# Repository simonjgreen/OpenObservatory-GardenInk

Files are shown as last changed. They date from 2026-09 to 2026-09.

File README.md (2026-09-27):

# Open Observatory · Garden Ink

An illustrated e-ink display for [Open Observatory](https://github.com/simonjgreen/OpenObservatory). A Raspberry Pi Zero, a printed frame, and an hourly account of what the garden has been up to.

**Garden Ink is an expansion of Open Observatory and depends on it for its data.** The outdoor station does the listening, identification and review. This is another way to see what it heard, on a screen that can sit in the kitchen and get on with it.

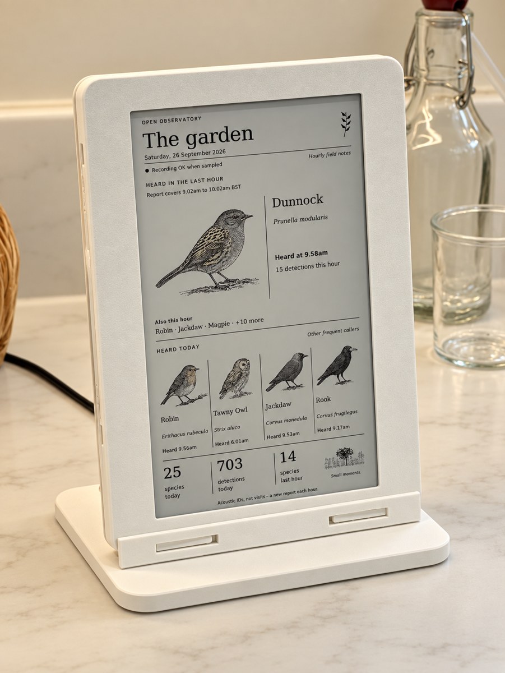
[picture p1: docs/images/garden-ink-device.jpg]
Garden Ink running on a portrait e-ink screen in its white printed Counterframe enclosure


*The assembled frame, running on the kitchen counter. The birds are illustrations of acoustic identifications.*

## Where the idea came from

I already had an [indoor LCD display for Open Observatory](https://github.com/simonjgreen/OpenObservatory#the-indoor-display): a small ESP32 touchscreen showing what the station was hearing outside. Then I saw [Fugleramme](https://github.com/arnegiacomo/fugleramme) on [Hacker News](https://news.ycombinator.com/item?id=49711544), and thought it'd be nice to have an e-ink version of my existing display. I mentioned [the LCD setup in the discussion](https://news.ycombinator.com/item?id=49719062).

Credit to [arnegiacomo](https://github.com/arnegiacomo) and Fugleramme for the e-ink idea. I already had the listening side working; seeing their bird frame made me want to give it a different sort of display. Garden Ink is the result.

## What it does

- Shows the latest qualifying identification from the last hour, alongside three other frequent species heard today, with wider cards for unusually long names.
- Uses the six-species Gallery for the 10am and 2pm local-time editions, returning to Journal at 11am and 3pm. Night mode takes priority; `gallery_hours` configures these daily slots.
- Refreshes on startup, then starts scheduled updates on the hour. `./service.sh refresh` requests an update between scheduled reports; startup and manual pushes retain a saved three-minute minimum between panel attempts. It shows the date and when things were heard; a clock that is wrong for most of the hour would be fairly unhelpful.
- Counts qualifying acoustic detections, with the station's review decisions and source filtering respected. Today starts at local midnight, including when the clocks change. If a scan is incomplete, the totals say so.
- Switches to a three-page bat and owl carousel after sunset when daytime bird detections fall and sustained bat activity or an owl is heard. It keeps the night edition until sunrise, with an owl portrait and bat illustration throughout. See [night mode](docs/design/NIGHT_MODE.md).
- Uses a Waveshare 7.3-inch Spectra 6 **HAT (E)** in 480 × 800 portrait orientation.
- Runs locally with cached artwork. Optional paid image generation is separate and disabled by default.
- Redraws the current page when one of its missing illustrations becomes available, retaining the three-minute panel guard and the regular report schedule.

One bird can produce plenty of detections, so the numbers aren't a count of individual birds or visits.

## The frame

The enclosure is called **Counterframe**. It stands on its own, prints in PLA and goes together without screws. There is one power lead into the Pi; everything else fits inside.

These are the four printed parts laid out before assembly: the front bezel, internal carrier, rear cover and stand.

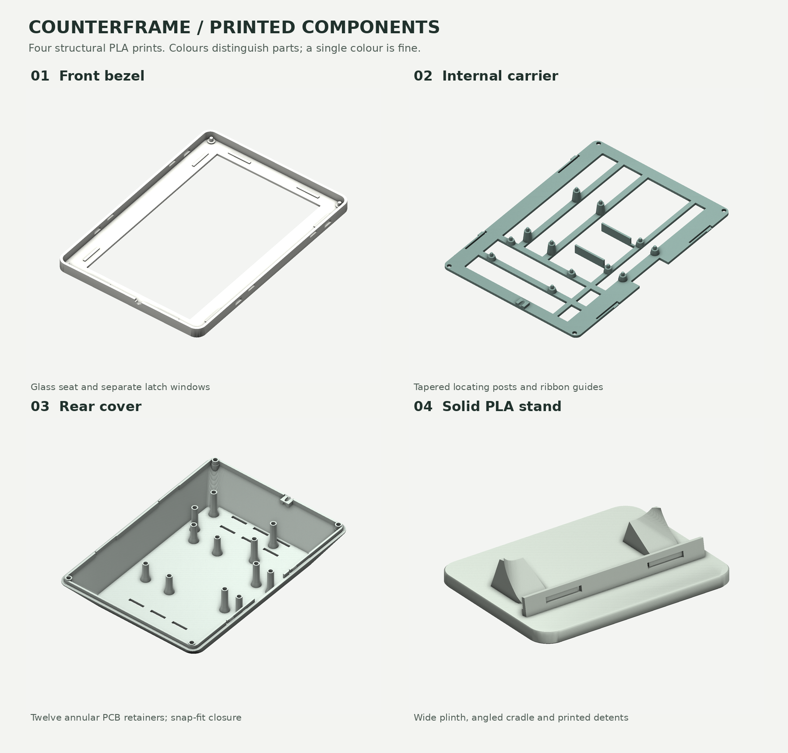
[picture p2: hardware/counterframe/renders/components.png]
CAD render of the four Counterframe parts laid out for assembly: front bezel, internal carrier, rear cover and stand


With the back removed, you can see where the Pi, display driver and adapter sit, and how the ribbon and power cable fit around them.

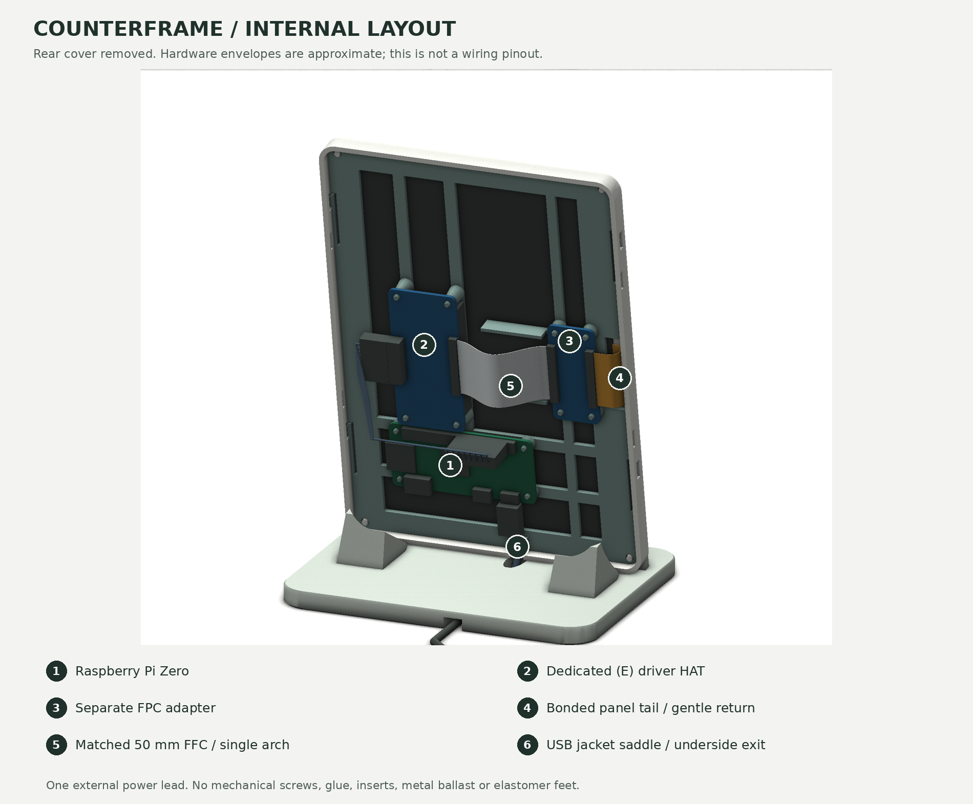
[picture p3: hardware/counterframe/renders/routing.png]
CAD render with the back removed, showing the Pi Zero, display driver, adapter, ribbon cable and USB power route


Both images are CAD renders from the [frame build guide](hardware/counterframe/README.md). The cable colours show the route through the case; use the [wiring table](docs/design/MECHANICAL.md#project-wiring) for the actual connections. The [OpenSCAD source and printable parts](hardware/counterframe/) are included.

## Requirements

You need a running [Open Observatory station](https://github.com/simonjgreen/OpenObservatory) that the display Pi can reach. Garden Ink reads its `/api/v1/health` and `/api/v1/detections` endpoints. The station is a separate installation; the [API contract](display/docs/API_CONTRACT.md) describes what the display expects from it.

The display requires a Pi Zero, Raspberry Pi OS, the specific HAT (E) panel and SPI wiring. Other Waveshare variants are not interchangeable. Workstation previews require Python 3.9+, Pillow and DejaVu fonts, with no station or API key.

## Try it on a workstation

```bash
git clone https://github.com/simonjgreen/OpenObservatory-GardenInk.git
cd OpenObservatory-GardenInk
python3 -m venv .venv
.venv/bin/python -m pip install -r requirements-dev.txt
make test PYTHON=.venv/bin/python
make preview PYTHON=.venv/bin/python
```

On Debian/Ubuntu, install `python3-venv`, `fonts-dejavu-core` and `fonts-dejavu-extra` if needed. Then open `local/previews/no-clock.png` to see the actual 480 × 800 output with labelled sample observations. You can try this without a panel, a live station or an API key.

## Install on a Pi

Copy `display/` to `~/garden_ink` on a fresh Pi, then run as the normal Pi user:

```bash
cd ~/garden_ink
./install.sh http://YOUR-STATION:8080
./run.sh --check
./run.sh --once
./service.sh install
```

For an existing device, first follow [deployment and backup](docs/operations/DEPLOYMENT.md). Preserve configuration, curated artwork, credentials, refresh state and the artwork spending ledger.

## Artwork

The original [robin](art_studio/reference/robin.png) is the reference for the ink-and-wash style. There are 47 bundled images, and the consistency still needs work. The workstation studio has a 53-species catalogue, with generation, review, approval and export. If you already have generated artwork, import it before paying to make it again.

The display works without an OpenAI key. New image generation is optional and paid, and the results need looking at: successfully producing a PNG says very little about whether the bird has the right number of legs. See the [artwork workflow](docs/artwork/WORKFLOW.md), [local recovery](docs/operations/LOCAL_RECOVERY.md) and [optional automatic artwork](docs/operations/AUTOART.md).

## Project layout

| Path | Contents |
|---|---|
| `display/` | Pi application, hardware driver, bundled illustrations and display tests |
| `art_studio/` | Workstation artwork tool and original style reference |
| `hardware/counterframe/` | OpenSCAD master, printable parts and illustrated build guide |
| `design/` | Selected visual reference and current renderer baseline |
| `docs/` | Current architecture, setup, maintenance and design guidance |
| `tests/`, `tools/` | Offline regression suites and development helpers |

The [documentation map](docs/INDEX.md) points to the detail. Next I want to improve the content, refresh timing, readability, power consumption and artwork. [Status and roadmap](docs/STATUS_AND_BACKLOG.md) records what works and what still needs checking.

## Contributing and licensing

See [CONTRIBUTING.md](CONTRIBUTING.md) for local checks and [SECURITY.md](SECURITY.md) for private reporting. Software is MIT-licensed; the enclosure is CC0. Artwork, photographs and third-party notices have separate terms described in [LICENSE.md](LICENSE.md).

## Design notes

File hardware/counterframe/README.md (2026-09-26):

# Counterframe / 7.3 E6

**Portrait countertop enclosure · four structural PLA prints · no screws**

Version 1.0 engineering prototype, 23 September 2026. Designed in OpenSCAD and exported to individual manufacturing STLs. The render images are produced from the same geometry, not concept illustrations of a different object.

> **Detailed physical fit qualification remains outstanding.** The project photograph shows an assembled device, but its exact print revision and measurements are not recorded. Published board outlines and mounting-hole positions have been checked; component heights, cable dimensions, bend suitability, print tolerances and real countertop stability still require first-article verification. Read the compatibility table before printing. Do not force the display or its bonded flex to fit.

## Design at a glance

The front is a softly rounded picture frame, with a 9 mm-deep perimeter and a rear housing that tapers to a smaller back face. The maximum enclosure depth is 34 mm. A separate low plinth holds the screen 10 degrees back from vertical. Boards are mounted beside one another rather than stacking the HAT on the Pi.

| Item | Nominal CAD dimension |
|---|---:|
| Front body | 134 × 188 mm |
| Maximum body thickness | 34 mm |
| Visible straight perimeter depth | 9 mm |
| Stand footprint | 142 × 108 mm |
| Main plinth thickness | 8 mm |
| Assembled height | Approximately 195 mm |
| Display opening | 96.8 × 160.8 mm, portrait |
| Image area | 96 × 160 mm, portrait |
| Shell wall / front face | 2.2 / 1.8 mm |
| Backward inclination | 10° |

The bezel centres the **visible image**, not the raw glass outline. The glass is offset by 2.9 mm relative to the image centre because the original panel's inactive borders are unequal. The wider side border also makes room for the bonded flex to return behind the display.

## Files

- `counterframe.scad`: editable master model; no external CAD library required.
- `stl/front.stl`, `carrier.stl`, `rear.stl`, `stand.stl`: print **one of each**.
- `stl/release_key.stl`: optional small PLA tool for pressing the release tabs.
- `stl/coupon_pins.stl`, `coupon_holes.stl`: peg-fit samples.
- `stl/coupon_latch.stl`, `coupon_socket.stl`: small snap-fit practice pieces.
- `renders/`: assembled, rear, side, internal, exploded and individual-part views.
- `BUILD_GUIDE.html`: illustrated offline guide; open in a browser.
- `validation.json`: mesh and nominal geometry check results, with their limitations.
- `export.sh`: reproduces the manufacturing STLs with the OpenSCAD CLI.
- `render.py` and `checks/export_render_meshes.py`: optional renderer; requires Python, VTK, NumPy and Pillow in addition to OpenSCAD. `reference/` contains **non-printing, approximate electronics and cable envelopes** used by it.

All manufacturing STLs are in **millimetres**, already oriented for printing. Do not merge them into a single print, scale them to fit a bed, or print the electronics reference meshes. The assembly and exploded selectors are for inspection, not a single printable object.

## Hardware compatibility: verify these first

This is specifically based on **Waveshare 7.3inch e-Paper HAT (E), E Ink Spectra 6**, with its separate small FPC adapter and dedicated blue driver HAT. It is **not** a claimed fit for the seven-colour (F), the four-colour (G), a generic e-Paper driver board, or a PhotoPainter board. [S1–S4]

| Hardware | Published outline / holes used | What still needs measuring |
|---|---|---|
| Display glass | 170.2 × 111.2 mm; active 160 × 96; model thickness 0.91 mm | Actual thickness, back-side features and allowable flex-bending region |
| Dedicated (E) HAT | 65 × 30.5 mm; 58 × 23 hole pitch; Ø3 mm holes | Underside header and top-side connector/switch heights |
| Small adapter | 45 × 21 mm; 38 × 14 hole pitch; Ø3 mm holes | Socket orientation, housing heights and any underside parts |
| Raspberry Pi Zero | 65 × 30 mm; 58 × 23 hole pitch; Ø2.75 mm holes | Your board revision, populated components and GPIO connector boots |

The Pi mounting pattern is taken from the official Pi Zero drawing. The component keep-out is a conservative **approximation**, not a manufacturer STEP model. A Zero 2 W may share the mounting outline, but this package does not certify every component of every Zero-family revision. Check your actual unit. [S5]

### Specific cable and connector assumptions

1. **One slim, straight micro-USB plug** into the Pi's **PWR IN** port. The modelled moulded body is 9.6 mm wide × 14 mm long × 5.6 mm thick; the cable jacket is Ø3.4 mm. A bulky boot, ferrite bead or right-angle connector is not an assumed fit. This does not add a USB-C panel socket or a USB extension inside the case.
2. **50 mm overall-length, 50-way FFC** between the adapter and HAT, with the correct pitch and contact-side arrangement for the kit. The modelled path is 50 mm including the seated ends. This is a **short interconnect**, not an attempt to fold a long kit cable into the case. The actual supplied cable length has **not** been established; obtain a matching short replacement when necessary. Measure yours; do not stretch a shorter cable to this route or compress a longer one into a tight crease. Preserve the manufacturer's contact orientation.
3. An eight-wire SPI/power lead connects the remote HAT to the Pi GPIO. The model permits female jumper housings extending 14 mm above the Pi header plastic. Follow the Waveshare pinout; the simplified wire colours and positions in the render are **not a wiring diagram**. No second external power supply is designed into the enclosure.
4. The short bonded panel tail is taken as 24 mm long × 25.5 mm wide from the drawing. Its modelled return has a **4.5 mm bend radius**. The separate 50 mm FFC follows one smooth arch with approximately 6.7 mm minimum modelled radius. These are **design assumptions, not manufacturer-approved minimum bend radii**. Reject the route if it would bend a stiffener, IC, bonded transition, or unsuitable portion of the actual tail. [S2, S6]

## How the retention works

### Front bezel and glass

The glass rests on its inactive front border inside broad lateral guides. It is captured between the bezel and the skeletal carrier with **0.15 mm nominal axial clearance** and **0.30 mm clearance per side**. There is no intended spring preload, press fit, conical peg contact or adhesive on the glass. The carrier must click home without squeezing or bowing it. The nominal backside air gap also separates the carrier crossbars from the glass.

### Internal carrier and boards

The carrier locates on four tapered bezel pins and locks into four side windows with long, in-plane flexure tabs. Each PCB sits on **four tapered-tip locating posts**. Their parallel locating portions are Ø2.50 mm for the Pi and Ø2.70 mm for the HAT and adapter. The taper is a lead-in, not a wedge driven into the PCB hole.

The rear cover has **twelve integral annular retaining collars** aligned with those posts. When the lid is fitted, these capture the mounting-hole lands from above with 0.15 mm nominal clearance. Central bores in the collars clear the peg tips. This separates lateral location from axial retention and avoids relying on friction in a PCB hole. The rear cover has separate hard stops over the four carrier fixings, relieved for the front locator tips.

The boards are intentionally **not retained against lifting while the cover is removed**. Assemble and service with the frame lying face-down, not standing vertically with loose boards hanging on pegs.

### Rear cover and stand

Four independent rear-cover snap tabs engage their own side windows. The front and carrier clips use different positions, so servicing the lid does not require releasing the glass carrier.

The stand has a fitted angled cradle, two rear buttresses and two detent leaves that engage recesses below the image. It is a separate part so its mass can be concentrated low down. Print it **solid PLA**: no metal ballast or rubber feet are required by the design.

PLA feet are not a substitute for rubber grip. The wide base is intended to resist tipping during modest movement, but the actual unit may slide on a polished or wet counter. This design has not been bump-, pull- or drop-tested. Lift it by the base rather than by the display bezel.

## Cable routing

Viewed **from the open rear**, the Pi is at the bottom, the driver HAT is above it on the left, and the small adapter is on the right.

- The display's short bonded flex exits the **right side in this rear view**, rounds back inside the side pocket and enters the adapter's outer socket. Seen from the front, this is the display's left edge.
- The white 50 mm FFC follows a single broad arch between the adapter and HAT. Its centreline travels monotonically from one socket to the other, so it has no crossing folds. It bends through its thickness, without an edgewise fold or twist. The carrier has fences beside this lane and the lid's retaining columns are outside the modelled route.
- SPI wires run left from the Pi **below the lower HAT mounting posts**, then up the left-hand side into the HAT's eight-pin connector. Do not pull them diagonally across the lid's collar positions.
- USB power enters the Pi directly, follows a shaped jacket saddle at the lower edge, and sweeps rearwards through the stand's open underside channel. The nominal jacket path uses **8 mm-radius bends**. Only this flexible jacket is lightly captured; the plug and PCB connector must not carry a cable tug.

The saddle follows the curved USB path and is split between the carrier and lid. A plug does not have to be pushed through a tiny printed hole. Its default groove is 0.10 mm smaller than the measured jacket diameter; set `cable_grip=0` initially when the jacket's compressibility is unknown. **Use the same setting to regenerate both carrier and rear cover.** Check that the jacket is held without flattening, cutting or levering the plug.

The cable guidance is not an industrial strain-relief rating. Leave slack behind the stand so a moved appliance or pulled lead does not load the micro-USB connector or topple the frame.

## Printing

Suggested starting point for a calibrated 0.4 mm-nozzle FDM printer:

| Part | Orientation in supplied STL | Starting settings / supports |
|---|---|---|
| Front | Visible face on bed | 0.16–0.20 mm layers, 4 perimeters, 5 top/bottom layers; no supports intended |
| Carrier | Flat grid on bed, posts upward | 0.16 mm layers, 4 perimeters, 100% infill; no supports intended |
| Rear | Outside back face on bed, collars upward | 0.16–0.20 mm layers, 4 perimeters, 5 top/bottom layers; no supports intended |
| Stand | Plinth on bed | 0.16–0.20 mm layers, 4 perimeters, **100% infill**; local PLA supports beneath the front detent leaves/tips |
| Coupons / key | As supplied | Same filament and fit-critical settings as the final parts |

These settings have **not** been sliced for your printer. Inspect the layer preview, especially the stand's free-ended detent leaves, cable-channel bridges and latch tips. Use local support painting rather than filling every cavity with support. Clear all support from the cable passage before inserting a cable.

A **200 × 200 mm usable bed** accommodates the largest 134 × 188 mm part, with a modest brim if the printer's actual usable area permits it. A 220 × 220 mm bed provides more margin. Do not scale parts to fit a smaller bed. Use filament-specific temperature settings and a clean bed; keep seams, first-layer bulges and support scars away from glass seats and mating faces.

Use ordinary unfilled PLA for the first article. Print coupons in the same spool and orientation. A decorative filament's snap behaviour can differ; no blend is certified here. Prusa notes PLA's relatively brittle behaviour and low temperature resistance. [S7]

### Calibration before the full build

The pin coupon has five nominal diameters, left to right along increasing X: **2.40, 2.50, 2.60, 2.70, 2.80 mm**. Its companion has three Ø2.75 and two Ø3.00 holes. Printed holes only indicate your printing process; they do not replace checking a real PCB hole. Gently test a suitable individual peg with the actual PCB, supporting it at the hole. A board should lower onto its posts without being forced or flexed.

For the latch coupon, place the male part on the socket's open floor with the long leaf next to its rear wall and press down until the small head enters the window. The male underside ends 1 mm above the socket's print-bed plane. Release by pushing the head inward through the window. This tests a similar in-plane PLA leaf, not the entire case or stand interface. Reject cracked, whitened or permanently distorted samples.

Dry-fit the four full-size printed parts **without electronics** before assembling the glass. All clips should engage with modest, local finger pressure. Do not compensate for a tight print by pushing harder through the screen. Correct dimensions or printing settings and reprint.

## Assembly order

1. Bench-test the Pi and display. Install the microSD card and any required GPIO header before enclosure assembly. Check every dimension in the compatibility section, the FFC contact orientation, and the physical bendable regions of both flex cables.
2. Print and test the coupons, then the four structural parts. Remove stringing and support debris; smooth only the relevant printed mating surfaces. Confirm the empty front, carrier, lid and stand fit without force.
3. Lay the front bezel face-down on a clean, protective work surface. Lower the glass into its seat, image toward the aperture, bonded tail to the right **as seen from the rear**. Keep dust and printing burrs off the glass support border.
4. Position the carrier on its four bezel locating pins. Keep the bonded tail outside the carrier's relieved side pocket. Engage the four carrier tabs using pressure on the perimeter near each clip, not the crossbars over the glass. Verify the display is not bowed or squeezed.
5. Place the Pi, HAT and adapter on their respective four locating posts. Check every PCB sits on its standoff shoulders, not on a component or cable. The HAT's factory underside header is retained; no desoldering is assumed.
6. Connect the panel tail to the adapter with a gentle return. Connect the 50 mm FFC and arrange the broad arched route. Insert and lock connectors according to the kit instructions. The full seated contact ends must remain straight; do not pull the bonded tail to gain reach.
7. Connect the eight-wire HAT lead to the Pi, following the manufacturer pinout. Route it around the left side of the HAT, below its lower retention-post positions. Plug the slim micro-USB lead into **PWR IN**, not the data USB port, and place its jacket in the curved lower saddle.
8. With the unit still face-down, lower the rear cover squarely. Make sure each annular collar surrounds a peg rather than landing on a component. Check the entire cable route before engaging all four lid clips. The cover must not require force to flatten a ribbon or push down a connector.
9. Lay the external USB lead into the stand's open underside channel. Seat the case into the angled cradle and engage the two front detents. Confirm the cable is not trapped between the case and the stand and does not lift the stand off the worktop.
10. Power up. Check a full image, then check temperature, stability, cable slack and the absence of glass pressure during normal use. Stop using the enclosure if the display changes when the frame is gently handled, a plug is under load, a latch cracks or the plastic distorts.

For service: unplug power; support the frame; release the two stand detents and remove the case. Lay it face-down. Press the rear-cover tabs inward using the supplied PLA key and lift the cover evenly. Do not pry between glass and bezel. Release the carrier only when the screen itself needs removal. Removing the lid also removes axial retention from the PCBs.

## Kitchen placement

This is a **vented indoor enclosure, not splash-proof, washable or IP-rated**. There is no transparent protective sheet over the display. Keep it away from the hob, oven exhaust, toaster, kettle plume, sink splashes and direct hot sunshine. Do not wash or immerse it. Prusa states that ordinary PLA can soften and deform above approximately 60°C; that is not an acceptable target operating temperature. [S7]

The solid base improves the distribution of mass but cannot guarantee resistance to a cable snag or a forceful knock. Confirm stability on your actual worktop, first with the screen supported. All-PLA construction deliberately excludes elastomer anti-slip feet.

## Editing and regenerating

Open `counterframe.scad`, select `part`, and use F6 to render. For a printable export choose `front`, `carrier`, `rear` or `stand`, then export STL. `assembly`, `exploded` and `section` are inspection views. Toggle `show_hardware` and `show_cables` for clarity.

```sh
# Reproduce all manufacturing STLs (OpenSCAD must be installed).
bash export.sh

# A single part, or a tolerance variant.
openscad -o carrier.stl -D 'part="carrier"' counterframe.scad
openscad -o rear_no_grip.stl -D 'part="rear"' -D 'cable_grip=0' counterframe.scad
```

The short FFC arch uses `ffc_arch_rise`; it is not a route for an arbitrary cable length. The most useful fit adjustments are `panel_t`, `panel_xy_clear`, `panel_z_clear`, `pi_peg_d`, `hat_peg_d`, `pcb_t`, `pcb_capture_clear`, `cable_d`, `cable_grip` and `fit`. Changing a mating dimension means regenerating **all affected parts**, not just one. Never shrink the glass pocket to obtain an interference fit.

This is an editable design for a particular hardware arrangement, **not a universally self-adapting enclosure generator**. Board positions, plug keep-outs and the arched-cable route include fixed values. Substantial dimension changes require checking those features and rerunning clearance checks. The optional Python studio renderer's transforms are set for this delivered version; update them for altered dimensions. OpenSCAD's own assembly view uses the live parameters.

## Validation scope

`validation.json` records the checks actually completed on the exported meshes. A watertight, single-body STL is not proof that a snap fit will survive printing or use. Nominal CSG interference checks use simplified hardware keep-outs, omit small components and solder details, and intentionally allow the specified USB jacket compression. They do not measure real strength, thermal behaviour, grip, electrical safety, cable bend limits, manufacturing variation or impact resistance.

Before relying on the enclosure, the remaining first-article checks are actual hardware fit; printing/slicing; latch engagement and release; no preload on the glass; fully seated, unstrained flex connectors; non-damaging USB capture; normal-use temperatures; and stability/cable-pull behaviour on the intended counter.

## Manufacturer references

Dimensions were checked against these primary sources on 23 September 2026. Published component heights and a full exact mechanical model were not available in the reviewed material.

- **S1 — Waveshare product identification:** https://www.waveshare.com/7.3inch-e-paper-hat-e.htm
- **S2 — Waveshare panel / active area / bonded tail drawing:** https://www.waveshare.com/img/devkit/LCD/7.3inch-e-Paper-HAT-E/7.3inch-e-Paper-E-details-size.jpg
- **S3 — Waveshare HAT and adapter mounting drawing:** https://www.waveshare.com/img/devkit/LCD/7.3inch-e-Paper-HAT-E/7.3inch-e-Paper-HAT-E-details-size.jpg
- **S4 — Waveshare assembly arrangement photograph:** https://www.waveshare.com/img/devkit/LCD/7.3inch-e-Paper-HAT-E/7.3inch-e-Paper-HAT-E-details-5.jpg
- **S5 — Raspberry Pi Zero mechanical drawing:** https://datasheets.raspberrypi.com/rpizero/raspberry-pi-zero-mechanical-drawing.pdf
- **S6 — Waveshare (E) manual, specifications and handling guidance:** https://www.waveshare.com/wiki/7.3inch_e-Paper_HAT_(E)_Manual
- **S7 — Prusa PLA material guidance:** https://help.prusa3d.com/article/pla_2062

**Required before the full print:** confirm the exact (E) kit, obtain/check the matched 50 mm FFC, and measure the USB plug and jacket.

Generated enclosure code and meshes: CC0-1.0. Manufacturer documentation, brands and trademarks remain their respective owners' material. The screen artwork is illustrative content, not supplied display software.

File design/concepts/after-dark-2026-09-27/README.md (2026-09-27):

# After-dark design concepts

Created 27 September 2026 with the built-in image generation tool. These are AI-generated visual targets with invented sample data, not actual Garden Ink renderer output or hardware-tested layouts. The portrait compositions target the 480 × 800 screen's 3:5 proportions. Bat artwork is concept art, not an anatomy-approved production asset.

1. 01-night-rhythm.png — hourly activity compared with recent-night median.
2. 02-seven-nights.png — same four-hour period across seven evenings.
3. 03-bat-field-journal.png — educational species spotlight with generic recorded activity.

References: design/previews/v2.1/no_clock.png for screen layout; art_studio/reference/robin.png is the sole original illustration style reference. No paid API key or artwork-generation ledger was used.

All counts and times are invented. The activity unit means one-minute bins containing a qualifying detection, not individual bats or continuous calling duration. Species spotlight content does not establish local species identification.

## Generation prompts

### 01-night-rhythm

Use case: ui-mockup. Create ONE polished flat front-on e-ink screen design, portrait aspect ratio exactly 3:5, ideally 960x1600 pixels (logical screen 480x800). Fill image with the screen only, no hardware frame, room, perspective, drop shadow or surrounding presentation board. This is a Garden Ink / Open Observatory after-dark concept.
Reference image 1 is the existing screen composition, typography and white editorial field-journal style. Reference image 2 is the ORIGINAL robin artwork and the sole art-style reference: render any BAT in equivalent fine black natural-history hatching and restrained muted ochre wash on pure white, accurate natural bat anatomy, never bird feathers or orange robin markings. Do not draw a robin. Bat illustration is decorative educational art, not an observed animal portrait.
Use crisp black text, elegant large serif title, readable sans-serif small labels, fine horizontal rules, generous whitespace. White paper without artificial texture, no inverted dark mode, no rounded cards, no gradients, no app controls. One restrained blue chart accent permitted. Screen should look beautiful and plausible at 480x800, not an overcrowded dashboard. Text carefully typeset and completely legible.
COMMON HEADER: small tracked 'OPEN OBSERVATORY'; large serif 'The garden'; elegant italic subtitle 'After dark'; 'Night of 27 September 2026'. Fine rule then a small status 'DEMO · invented observations'. Clear historical interval 'Report covers 6.45pm–10.45pm BST'. These are historical sample times, no free-standing clock, no current time widget.
COMMON FOOTER: small 'Concept preview · sample data, not your garden'. Never label detections as individual bats, visits or songs. No claims of local bat species identification. No fabricated live status.

CONCEPT 1: THE NIGHT'S RHYTHM. Main hero is a large exceptionally readable chart, taking central 40% of screen, with heading 'THE NIGHT’S RHYTHM'. Subheading 'Minutes with bat detections'. Four solid narrow blue bars for completed hours after sunset with values 12, 23, 17, 8, plotted accurately on scale 0 to 30 with ticks 0, 10, 20, 30. X-axis category labels '0–1', '1–2', '2–3', '3–4'; beneath axis 'Hours after sunset'. Thin black dashed comparison line with points at 9, 15, 12, 8. Compact legend 'Tonight' (blue square) and 'Previous 7 nights · median' (dashed black). Keep chart generous and clean, no future bins. Below graph one serif takeaway: 'Most activity in the second hour'. Then a ruled two-column stat strip: large '60' with label 'minutes with detections'; large '+24 min' with label 'first recorded after sunset'. Bottom educational field note with small flying pipistrelle-like bat on left and text on right: heading 'AUTUMN FIELD NOTE', body 'Bats build fat reserves ahead of winter.' Below small explanation 'Each minute counted once; not a count of bats.' This concept should be graph-led, calm, attractive, and grounded in the original editorial screen.

### 02-seven-nights

Use case: ui-mockup. Create ONE polished flat front-on e-ink screen design, portrait aspect ratio exactly 3:5, ideally 960x1600 pixels (logical screen 480x800). Fill image with the screen only, no hardware frame, room, perspective, drop shadow or surrounding presentation board. This is a Garden Ink / Open Observatory after-dark concept.
Reference image 1 is the existing screen composition, typography and white editorial field-journal style. Reference image 2 is the ORIGINAL robin artwork and the sole art-style reference: render any BAT in equivalent fine black natural-history hatching and restrained muted ochre wash on pure white, accurate natural bat anatomy, never bird feathers or orange robin markings. Do not draw a robin. Bat illustration is decorative educational art, not an observed animal portrait.
Use crisp black text, elegant large serif title, readable sans-serif small labels, fine horizontal rules, generous whitespace. White paper without artificial texture, no inverted dark mode, no rounded cards, no gradients, no app controls. One restrained blue chart accent permitted. Screen should look beautiful and plausible at 480x800, not an overcrowded dashboard. Text carefully typeset and completely legible.
COMMON HEADER: small tracked 'OPEN OBSERVATORY'; large serif 'The garden'; elegant italic subtitle 'After dark'; 'Night of 27 September 2026'. Fine rule then a small status 'DEMO · invented observations'. Clear historical interval 'Report covers 6.45pm–10.45pm BST'. These are historical sample times, no free-standing clock, no current time widget.
COMMON FOOTER: small 'Concept preview · sample data, not your garden'. Never label detections as individual bats, visits or songs. No claims of local bat species identification. No fabricated live status.

CONCEPT 2: SEVEN NIGHTS IN THE GARDEN. Hero heading 'SEVEN NIGHTS' followed by large serif 'An evening in context'. Small explanation 'First four hours after sunset, each night'. Main center has seven elegant HORIZONTAL bars with date at left and value at right; all share exactly same scale starting at zero. Values accurately proportional: '21 Sep' 38, '22 Sep' 44, '23 Sep' 31, '24 Sep' 47, '25 Sep' 52, '26 Sep' 41, '27 Sep' 60. Previous six bars black with finely hatched fill, last tonight bar muted blue solid. No unnecessary y axis ticks because numbers explicitly shown. Label axis/measure 'Minutes with bat detections'. Clearly highlight final row as '27 Sep · tonight' if space permits. Ample vertical space between rows and no card boxes. Below ruled chart large serif conclusion 'The busiest of these seven evenings' and smaller 'Compared over the same four-hour window.' Small art vignette of a natural-history flying bat beneath or beside the conclusion, restrained and subordinate. Bottom slim stat row '7 comparable evenings' and '60 minutes tonight'. Note 'Each minute counted once; not a count of bats.' Visually different from concept 1: a seven-row archive/comparison, no line graph. Maintain white editorial paper aesthetic and restrained print typography.

### 03-bat-field-journal

Use case: ui-mockup. Create ONE polished flat front-on e-ink screen design, portrait aspect ratio exactly 3:5, ideally 960x1600 pixels (logical screen 480x800). Fill image with the screen only, no hardware frame, room, perspective, drop shadow or surrounding presentation board. This is a Garden Ink / Open Observatory after-dark concept.
Reference image 1 is the existing screen composition, typography and white editorial field-journal style. Reference image 2 is the ORIGINAL robin artwork and the sole art-style reference: render any BAT in equivalent fine black natural-history hatching and restrained muted ochre wash on pure white, accurate natural bat anatomy, never bird feathers or orange robin markings. Do not draw a robin. Bat illustration is decorative educational art, not an observed animal portrait.
Use crisp black text, elegant large serif title, readable sans-serif small labels, fine horizontal rules, generous whitespace. White paper without artificial texture, no inverted dark mode, no rounded cards, no gradients, no app controls. One restrained blue chart accent permitted. Screen should look beautiful and plausible at 480x800, not an overcrowded dashboard. Text carefully typeset and completely legible.
COMMON HEADER: small tracked 'OPEN OBSERVATORY'; large serif 'The garden'; elegant italic subtitle 'After dark'; 'Night of 27 September 2026'. Fine rule then a small status 'DEMO · invented observations'. Clear historical interval 'Report covers 6.45pm–10.45pm BST'. These are historical sample times, no free-standing clock, no current time widget.
COMMON FOOTER: small 'Concept preview · sample data, not your garden'. Never label detections as individual bats, visits or songs. No claims of local bat species identification. No fabricated live status.

CONCEPT 3: BAT FIELD JOURNAL. Illustration-led alternative. Beneath common header, small tracked 'FROM THE BAT FIELD GUIDE' then large serif 'Common pipistrelle' and italic 'Pipistrellus pipistrellus'. Prominent educational qualifier 'Species spotlight · not identified by this station'. Large stunning original natural-history illustration of a common pipistrelle in flight, taking middle third of page, both membranous wings fully visible, two wings, two hind feet, subtle tail membrane, small furry body, modest rounded ears, accurate non-cartoon face. Anatomically credible slender elongated finger supports in wing membranes; fine black pen hatching and very restrained warm brown/ochre wash matching the original robin reference. White background, no branches, scenery, insects, moon or birds. Carefully composed wingspan with generous margins.
Under illustration readable short fact: 'A tiny bat at home in gardens.' then 'Common pipistrelles often emerge around twenty minutes after sunset.' Small attribution 'Field guide: Bat Conservation Trust'.
Then a thin horizontal rule separates education from local data. Heading 'RECORDED IN THIS REPORT' followed by two columns: large '60' label 'minutes with bat detections', and large '+24 min' label 'first recorded after sunset'. Under this a modest four-bar spark chart with accurately proportional heights 12,23,17,8, caption 'Recorded activity · first four hours after sunset'. Closing qualification 'Generic bat activity; species not determined.' This option feels like a treasured illustrated field-guide page with supporting records, substantially more artwork than the two charts.

## Field-journal axis correction

The third output was edited only to replace incorrect generated clock-hour labels with elapsed-hour labels. It was an edit target, not a new art style reference.

Edit ONLY the four x-axis labels on the small bar chart near the bottom of this image. Replace '6–7pm', '7–8pm', '8–9pm', '9–10pm' respectively with '0–1 h', '1–2 h', '2–3 h', '3–4 h'. They represent hours after sunset, matching the caption below. Preserve everything else exactly: entire layout, all other text, bat illustration, colors, white background, bars and their heights/values 12,23,17,8, header, historical report interval and demo disclaimer. Same portrait 3:5 dimensions. Do not add new text or change the artwork.

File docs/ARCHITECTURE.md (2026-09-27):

# Architecture and ownership

## The full system

```text
Garden microphone + detector station (OpenObservatory; separate repository)
    GET /api/v1/health and GET /api/v1/detections
             |
             v
Pi Zero: garden-ink.service                  Developer workstation
  bounded newest-first scan                 art_studio/studio.py
  canonical source/review filtering           manual, explicitly paid generation
  independent today/last-hour aggregation     one original robin reference
  no-clock Pillow renderer                    raw/prepared images + JSON state
  palette pack + single SPI owner              human approval + alias-aware ZIP export
             |                                           |
             v                                           v
  800×480 native panel buffer <--- local curated assets/custom/*.png
  hourly refresh, controller sleeps
             |
  metadata-only missing-art queue (real successful frames only)
             v
  state/autoart/jobs.sqlite3
             |
             v
Pi Zero: garden-ink-art.service (separate; optional)
  disabled until explicit paid opt-in
  two request workers, globally spaced starts, durable request-slot reservations
  OpenAI /v1/images/edits with robin reference
  raw response -> local preparation -> candidate/review -> published PNG
             |
             +----> state/autoart/images/ (display watches relevant missing art)
```

No browser, Docker, database server, image model runtime or display server is required on the Zero. The detection station remains the authority for acoustic records and human reviews. Generation is remote; the Zero does not run a generative model.

## Module map (`display/gardenink/`)

| Module | Owns |
|---|---|
| `config.py` | Validated settings, root path, URL normalisation, local token lookup and source/filter identity. |
| `client.py` | Bounded HTTP GETs, health parsing, pagination, tie handling, incremental reduction and completeness proof. |
| `model.py` | UTC/local time boundaries, eligibility, per-window species aggregation, status semantics. |
| `storage.py` | Atomic metadata and cached/empty snapshots; cached data retain their original bounds. |
| `render.py` | 480×800 no-clock composition, scientific/common names, historical times, current gallery compatibility. |
| `palette.py` | Native palette mapping, portrait rotation and packed two-pixels-per-byte transmission buffer. |
| `hardware.py` | The known-working HAT (E) reset/register/refresh/sleep path, GPIO import isolation and BUSY timeout. |
| `app.py` | CLI, global hardware lock, on-the-hour report scheduling, relevant-artwork redraws, persisted panel cooldown, snapshot/image saves and metadata-only post-frame enqueue. |
| `artfiles.py` | Canonical scientific-name handling and custom/generated/bundled asset lookup. |
| `autoart.py` | SQLite job/attempt state, concurrency, spending reservations, publish/recover behaviour. |
| `image_request.py` | Fixed-provider HTTPS request, reference/style fields, decode/preparation safeguards and error classification. |
| `autoart_cli.py` | Explicit enable/disable/key setup, worker, inspection, approval, rejection, retry/recovery/resume. |
| `demo.py` | Explicitly invented examples for offline rendering/tests. |

The workstation studio is intentionally separate and has its own original prompt fingerprint and state format. Sharing the artistic reference does not make the two recovery ledgers interchangeable.

## Time and counting contracts

Daytime page selection defaults to Journal, with Gallery during the local 10:00–10:59 and 14:00–14:59 editions (`gallery_hours: [10, 14]`). Normal hourly updates return to Journal at 11:00 and 15:00. Selection uses the current edition time in the configured timezone, so startup/manual reports during a slot agree with the scheduled report and DST changes preserve the local hours. It adds no refreshes or timers. A qualifying/latched night page takes precedence. Existing explicit alternating rotation takes precedence over the daily slots; `layout: gallery` still keeps Gallery outside the slots. Set `gallery_hours: []` to disable the slots, or supply other distinct integer hours from 0 to 23. `--layout` disables the daily slots for that run, retaining the existing night/rotation priority. Artwork-only redraws retain their original layout. Changing these display-only hours does not invalidate cached observations or the night latch.

On startup/restart, the service requests a fresh frame after a persisted 180-second minimum between attempts. With the default `refresh_seconds: 3600`, subsequent automatic reports start fetching at local `HH:00`, including local midnight and both occurrences of an autumn repeated hour. Long-running cycles skip missed boundaries rather than replaying them; clock corrections re-align the schedule.

Fetching, rendering and physical panel refresh take time: `HH:00` is the start of the update cycle, not a promise that the pigment has settled. Scheduled frames retain the configured interval between attempts. Startup and explicit `--refresh-now` requests use the 180-second minimum, checking the saved attempt time before fetching and again before driving the panel. They persist `attempt_kind: push` before hardware access; the next scheduled frame may resume after that minimum rather than being delayed by another full interval. Failed attempts receive the same protection, counters are never reset, and a backward clock correction restarts the applicable guard. `./service.sh refresh` safely restarts the service to request its startup frame. `--refresh-now` is a one-frame CLI command for use with the service stopped; `--once` retains the ordinary saved interval. Previews and checks remain immediate and do not touch hardware.

The report endpoint is fixed once per edition, preferably anchored to the station health timestamp. Queries cover the union of local today and the last hour, so shortly after midnight yesterday's final minutes may feature above an empty daily list. Event starts at the left edge are included; the report endpoint is exclusive. All arithmetic is timezone-aware.

Between reports the display checks missing image slots every 30 seconds. A newly published image for a pictured species redraws the same snapshot and layout after the persisted 180-second guard; it does not fetch observations, advance the report date, rotate layouts or queue paid work. Text-only mentions and species outside the current page do not trigger redraws. Candidates awaiting review are outside the artwork lookup. The next scheduled report takes priority over pending artwork, including at midnight; custom report intervals also keep their existing deadline. Hardware successes still increment `cycle`, while `edition` tracks report/layout progression independently. Artwork attempts persist `attempt_kind: artwork` before driving the panel, so the next report retains the minimum guard without waiting another full reporting interval.

Counts are records, never population estimates. Unreviewed model results use `min_score` (0.75 default); low-score human confirmations/corrections remain eligible, so the client must not naively filter them out at the server. Synthetic/replay/unknown streams, non-birds, withdrawn/rejected claims and malformed corrections are excluded. No claim of complete historical microphone coverage is made.

Partial data are not silence and do not become exact totals. Each window has its own completeness flag.

## Persistence boundaries

| Path on Pi | Meaning | Preserve during upgrade? |
|---|---|---|
| `config.json` | Site URL, filters, orientation and timezone | Yes |
| `token.txt` or configured token path | OpenObservatory credential | Yes, privately |
| `.secrets/openai-api-key` | OpenAI credential | Yes, privately |
| `autoart.json` | Opt-in and request limits | Yes |
| `assets/custom/` + manifests/catalogue | Reviewed/custom illustration library and aliases | Yes |
| `state/display.json` | Last physical attempt/cooldown | Yes |
| `state/snapshot.json` | Last report for offline rendering | Yes |
| `state/autoart/jobs.sqlite3` (+ WAL/SHM while active) | Durable job and spending history | Yes; coherent backup |
| `state/autoart/raw`, `candidates`, `images` | Paid output/review/publication | Yes |

Deleting the ledger or cooldown is not a supported fix for a failing request or a waiting display. Back up stopped services or use a coherent SQLite backup; do not copy only the main database while discarding an active WAL.

## Hardware/software boundary

The case uses an eight-wire SPI/power connection, not a HAT stacked on the Pi's 40-pin header. Power is one external micro-USB connection to Pi PWR IN. Device bounds and cable geometry in CAD are nominal approximations. The wiring authority for this project is [mechanical guide](design/MECHANICAL.md), the vendor references in the construction guide, not the simplified wire colours in the CAD render.

## After-dark reports

`solar.py` calculates local sunset/sunrise instants. `night_client.py` adds bounded, filtered night scans using the existing read-only transport; `night.py` owns bat policy, recording coverage, reduction and pure edition selection. `night_render.py` renders the three portrait pages, with `night_demo.py` supplying labelled offline fixtures. The day client remains independent for artwork-worker compatibility.

The display stores its night latch/page under `night` in `state/display.json` only after a successful hardware refresh. An attempted frame still saves its physical cooldown first. Artwork-only redraws retain the report and page. Failed night reads can retain the original cached night bounds, explicitly labelled as cached. Missing data cannot create a latch. See [night mode](design/NIGHT_MODE.md).

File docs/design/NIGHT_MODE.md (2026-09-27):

# After-dark carousel

Approved direction, 27 September 2026: keep the bird journal by day and enter the illustrated bat/owl carousel after local sunset when daytime birds quieten and either sustained bat activity or an owl is heard. Keep both bat and owl artwork, use detection counts, and omit repetitive biological caveats. Historical report bounds and actual operational failures remain honest.

## Switching and persistence

At each existing refresh, compare the latest 30 minutes of qualifying daytime bird records (excluding owls) with the rate in the hour before sunset. Quiet means at most 25% of that baseline rate, or at most two records in the recent half hour. Bat activity means at least ten qualifying records across at least three five-minute bins in the recent half hour. An eligible owl record since sunset is an alternative to the bat threshold. These thresholds are configurable starting values.

Use geometric local sunset with refraction convention (solar centre -0.833 degrees), not civil dusk. Source coordinates come from read-only station state or explicit configuration. Use UTC for elapsed windows and local dates for evening identity. No coordinates or trustworthy solar window means no automatic transition.

Require complete trigger scans, recent microphone coverage and healthy available detection pipelines before inferring bird quietness. Do not equate a complete API scan with recording coverage. Persist a latch keyed by evening date and station/filter identity until the following sunrise. Missing data holds a previously selected night edition; it never creates a new latch. Startup/manual refresh continues to follow the existing saved panel guard. Preview/check must not mutate the latch or carousel.

Cycle rhythm, history, journal on successful scheduled editions. Repeated pushes within an edition must not race through pages. Bring the owl journal forward once for a newly heard owl species, then resume. Recheck solar exit at the next normal refresh. Bird local-midnight/trailing-hour aggregation remains unchanged.

## Data and display

Read raw bat and bird detection records with source/review/withdrawal filtering. Generic ultrasonic bat passes need a separate score policy from species-ranked birds. Bounded scans must disclose incomplete totals with a plus suffix and withhold unsupported baselines. Compare only equal completed elapsed periods after each night's own sunset; future intervals and missing nights are gaps. Use recent recording coverage and compatible detector identities when deciding whether historical data can be compared; never silently reuse the station's unfiltered group roll-ups.

Three actual 480×800 pages target design/concepts/after-dark-bats-and-owls-v3. Reuse existing owl artwork through the normal curated-first lookup. Import a bat asset from the approved concept rather than adding paid API calls. Daytime hardware driver and artwork generation services are unchanged.

## Implementation and validation plan

1. Add offline tests for independent bat filtering, UTC solar windows, trigger boundaries, owl exclusion/exception, missing recording data, latch restart/sunrise and carousel stability.
2. Implement a separate night reducer and bounded night client using existing read-only transport. Keep day reduction and cache contracts compatible; add validated night settings and diagnostic output.
3. Implement three deterministic native-palette pages and labelled offline night demo fixtures. Validate dimensions, missing/partial data, long labels and all three rendered images.
4. Integrate selection/persistence around existing refresh flow, preserving cooldown and failed-attempt semantics. Test preview/check no-state writes and cached-night behaviour.
5. Run make verify and generated-unit verification; independently review changes, inspect previews, and correct substantive findings.
6. Deploy only reviewed files to the confirmed Pi with a private backup and state/artwork preservation, then check service logs without claiming unseen physical testing.

## Work log

- Existing uncommitted startup/manual-refresh, colour-wash and related documentation/tests predate this feature. Work in place to retain those approved changes; do not overwrite or revert them.
- Initial sandbox test run: local mock HTTP socket binds denied; rerunning the same offline suite with socket permission. No application failure established by that run.
- User's “ship it” authorizes implementation and delivery of the agreed design. Deployment target confirmed as `192.168.1.89`, installed at `/home/simon/garden_ink`.

## Configuration and previews

Night mode is enabled by default. `night_mode: false` restores day-only selection. Coordinates are read from station pipeline diagnostics unless both `latitude` and `longitude` are supplied explicitly. `night_bird_ratio`, `night_bird_quiet_count`, `night_bat_count` and `night_bat_bins` set the thresholds above; `bat_min_score` defaults to 0.5. `night_coverage_fraction` defaults to 0.9 and `night_max_pages` bounds the additional raw-record scan. These reads do not change station configuration.

From the checkout, use `PYTHONPATH=display .venv/bin/python display/dashboard.py --demo --preview --night-page rhythm --output local/previews/night-rhythm.png`; substitute `history` or `journal` for the other pages. The samples are labelled. `--night-page` is restricted to preview/check, so it cannot force a physical night transition. Live `--check` includes night data and trigger diagnostics. Preview and check never advance the persisted carousel.

Previous nights use equal completed hours after their own sunset. Without historical detector-effort records, an all-zero historical window cannot prove that bat analysis ran; such nights remain gaps. Comparable windows require adequate native-rate microphone coverage and matching observed detector versions. This is a detection-count comparison, not a weather-adjusted measure of the population.

## Verification record

27 September 2026: 324 offline tests passed with `make verify`, including source/review filtering, DST/midnight solar windows, carousel persistence, failed frame attempts, partial comparisons and three native 480×800 renders. An independent review's two findings were corrected: missing current recording coverage suppresses medians, and partial descending scans no longer claim a first detection time. The Pi's installed systemd unit passed validation. Live read-only testing exposed lifetime stream discontinuity counters; coverage now uses window-scoped missing-frame evidence instead. No paid image requests were made.

The first transfer was interrupted before connecting by a Pi reboot at 11:58:38 BST, consistent with the reported shared-USB power interruption. Deployment resumed after recovery with a fresh private backup at `/home/simon/garden_ink-private-night-20260927-1205.tar.gz`. All ten installed release files matched their hashes, and all 70 protected files (configuration, curated art, hardware driver and saved state) were unchanged before restarting services. The installed Pi application passed compilation, service-unit validation, a live daytime check and all three 480×800 sample renders. Both services restarted at 12:08 BST. The driver logged a completed 28-second panel refresh at 12:08:59, then panel sleep and the next scheduled report at 13:00; both services remained active. Release and manifest remain private in `local/`. An isolated read-only replay returned 626 filtered bat detections, owl records and seven usable comparison nights; this was a historical API compatibility check, not an observed dusk transition.

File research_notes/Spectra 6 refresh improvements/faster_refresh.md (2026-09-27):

# Faster pigment refresh on 7.3-inch Spectra 6 / Waveshare HAT E

## Do fast initialization or image simplification reliably shorten the flash?

### Takeaway
There is conflicting community evidence, so an assurance that software cannot shorten the flash would be too strong. One exact-model owner found no benefit from fast initialization or black-and-white content; separate Waveshare PRs report a much shorter refresh and need evaluation with clearly separated timing phases.

### Cited Findings
- In October 2025, a Waveshare WS-27875 / 7.3 HAT E owner reported trying Waveshare and Good Display examples, including an initialization sequence marked fast. They measured approximately 19–20 seconds from the final display-refresh command (DRF) to BUSY becoming idle, regardless of color or initialization code; uploading the picture added roughly another second. This is a useful first-person hardware report with a defined measurement boundary, not a controlled multi-unit study. — [Core Electronics thread](https://forum.core-electronics.com.au/t/7-3-6-color-epd-refresh-rate-ws-27875/23398)
- Other replies suggested simpler images or black-and-white output, but supplied no measurements for this panel. The original tester's measurements did not support that suggestion. The tester's speculation about a theoretical minimum or changing factory waveform must not be presented as established fact. — [Same first-person discussion](https://forum.core-electronics.com.au/t/7-3-6-color-epd-refresh-rate-ws-27875/23398)
- Waveshare PRs report 12.932 → 6.746 seconds, relevant counterevidence that merits consideration. The [implementation notes](implementation.md) cover the changes and limitations of the timing evidence. — [PR 387](https://github.com/waveshareteam/e-Paper/pull/387), [PR 389](https://github.com/waveshareteam/e-Paper/pull/389)
- Official Python epd7in3e driver sends image data first, then POWER_ON, DISPLAY_REFRESH, waits on BUSY, and POWER_OFF. Its BUSY polling interval is only 5 milliseconds. Speeding image transfer or reducing post-refresh sleep can reduce end-to-end execution without necessarily reducing flashing. — [Waveshare Python source](https://raw.githubusercontent.com/waveshareteam/e-Paper/master/RaspberryPi_JetsonNano/python/lib/waveshare_epd/epd7in3e.py)

### Inferences
- Measure preparation, SPI upload, and DRF-to-BUSY separately before judging any speed patch. This avoids attributing a faster upload to faster pigment movement.
- A normal black-and-white image sent through the unchanged six-colour update path is not a demonstrated flash-reduction workaround.

### Gaps
- No controlled repeatable benchmark across HAT E production revisions was found.
- No reviewed evidence here establishes a universal 6.7-second result, preserved color quality, or long-term safety of the PR changes; consult companion implementation notes.

## Why do credible sources report 12, 19, 25, or 28 seconds?

### Takeaway
Different panel revisions and timing boundaries explain at least some variation. Twelve seconds is not simply imaginary: the GxEPD2 author recorded that scale of pigment timing, but it is not a guarantee for later units.

### Cited Findings
- Current GxEPD2 GDEP073E01 header records an example full-refresh measurement of 12,468,000 microseconds, with both full and partial fallback time constants set to 15,000 milliseconds and fast-partial capability false. These constants are not a claim that every panel refreshes in exactly 15 seconds. — [GxEPD2 header](https://raw.githubusercontent.com/ZinggJM/GxEPD2/master/src/epd7c/GxEPD2_730c_GDEP073E01.h)
- Good Display currently lists 15–22 seconds full refresh for its GDEP073E01 panel. — [Manufacturer product page](https://www.good-display.com/product/533.html)
- Pimoroni currently lists its 7.3-inch Spectra 6 Inky Impression at 28 seconds core refresh. Its revision history says units made from April 2026 use a new AC-waveform panel with a slower core update in return for better color and less ghosting. The page gives 20–35 seconds as a realistic complete cycle across sizes/revisions and notes that cooler temperatures lengthen refresh. The 12-second footnote refers to manufacturer core timing at 25–50°C. This is adjacent hardware, not proof that the user's Waveshare contains that revision. — [Pimoroni current product and revision history](https://shop.pimoroni.com/products/inky-impression)

### Inferences
- Panel label/revision and ambient temperature belong alongside timing data when comparing results.
- Buying another nominally identical 7.3-inch Spectra 6 panel does not guarantee a faster update; newer can be slower for improved image quality.

### Gaps
- The user's exact panel revision and pigment-only elapsed time are not established in this research.
- I found no demonstrated, reproducible temperature-spoofing workaround specifically validated on the 7.3 HAT E. Temperature dependence is not a recommendation to heat the artwork display or spoof its sensor.

## Are there dramatic waveform hacks elsewhere that could transfer?

### Takeaway
Yes, adjacent Spectra 6 experimentation exists, but the striking subsecond example sacrifices the intended full-colour image. It is not a suitable drop-in improvement for Garden Ink artwork.

### Cited Findings
- FreeInk's native driver for M5Stack PaperColor (4-inch, 400×600 Spectra 6, ED2208) interrupts the normal approximately 15-second waveform at about 340 milliseconds to obtain a monochrome reading mode. Its authors say proper white and full color require a complete waveform; interrupted operation can visibly darken the display over hours as charge accumulates, so periodic complete waveforms are necessary. This is author-reported behavior for a different panel and device. — [FreeInk PaperColor behavior](https://github.com/Free-Ink/freeink-sdk#M5Stack-PaperColor-refresh-behavior)
- Glider's technical overview distinguishes Spectra 6 Plus as capable of faster operation with driver circuit changes; it is not presented as a software switch for a regular Waveshare HAT E. — [Glider technical overview](https://github.com/Modos-Labs/Glider)

### Inferences
- The adjacent 340ms hack should not be offered as a way to preserve the existing robin artwork while making its update subtle.
- A waveform trial on the actual HAT E should be judged on color, ghosting, and unchanged-region artifacts as well as elapsed seconds.

### Gaps
- No evidence found that FreeInk's interrupted-refresh method has been validated on the user's HAT E.
- Region-limited refresh is covered in the [partial-refresh notes](partial_refresh.md); this speed note should not be read as saying that partial refresh is impossible.

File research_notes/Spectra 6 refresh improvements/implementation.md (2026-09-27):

# Spectra 6 implementation evidence

## What concrete community code exists for partial refresh?

### Takeaway
There is concrete source for spatial partial refresh, including an unmerged patch to Waveshare's exact `epd7in3e.py` module. That is promising evidence for reducing flashing area, but it is not proof that the installed Garden Ink panel revision supports it.

### Cited Findings
- GxEPD2 1.6.8 added GDEP073E01 partial update on 16 March 2026. The maintainer says his other six/seven-colour screens ignore command `0x83`; another user reports four unspecified Spectra6 revisions working. The latter is a community report, not universal compatibility proof. — [Maintainer discussion](https://github.com/ZinggJM/GxEPD2/discussions/161)
- Current GxEPD2 GDEP073E01 source sends `0x83` with coordinates before data transfer and refresh; partial refresh sets border floating with `0x50=0xFF` and uses the normal `0x12` refresh command. Native packed pixels are aligned to two-pixel boundaries; bitmap paths align to eight. `_setPartialRamArea` contains a controller-specific Y endpoint adjustment (`y+h`, commented “one more”). — [Source, methods around lines 312–410 and 443–498](https://github.com/ZinggJM/GxEPD2/blob/master/src/epd7c/GxEPD2_730c_GDEP073E01.cpp)
- Header explicitly sets `hasPartialUpdate=true`, `hasFastPartialUpdate=false`; full and partial refresh timing constants are both 15000ms. This implements a full waveform in a restricted area rather than a quick monochrome-style update. — [Header lines 19–30](https://github.com/ZinggJM/GxEPD2/blob/master/src/epd7c/GxEPD2_730c_GDEP073E01.h)
- Good Display calls its downloadable ESP32 example “Full update within a specified area”; its download page is dated 25 August 2025. — [Vendor sample](https://www.good-display.com/companyfile/1908.html)
- Waveshare PR #389, opened 6 May 2025 and still open when checked 27 September 2026, adds `displayPartial(image,x,y,w,h)` directly to `epd7in3e.py`. It uses `0x83`, sends the pixels, and calls its normal update function. Its code differs from GxEPD2: Y end is `y+h-1`, and it prefixes the pixel data with a `0x00` byte. These are implementation details needing review and hardware validation, not a copy/paste recipe. — [PR](https://github.com/waveshareteam/e-Paper/pull/389); [branch source lines 174–183](https://raw.githubusercontent.com/missionfloyd/e-Paper/spetra6-performance/RaspberryPi_JetsonNano/python/lib/waveshare_epd/epd7in3e.py)
- The examined GxEPD2 implementation uses window coordinates, not per-pixel no-change masking. It maps native colour code `0x7` with a “white” comment; it does not establish `0x7` as a retain-pixel code. — [Source end of file](https://github.com/ZinggJM/GxEPD2/blob/master/src/epd7c/GxEPD2_730c_GDEP073E01.cpp)

### Inferences
- Keeping an unchanged bird illustration outside the refresh rectangle could substantially improve perceived calm, even if changing text still flashes for the ordinary waveform duration. Multiple scattered changes, rotation, and panel window alignment will affect which area must flash.
- The supplied code is enough to justify considering an opt-in experiment, but not enough to enable partial refresh in production by default.

### Gaps
- Neither examined PR conversation specifies the exact tested HAT/panel revision or demonstrates the particular Garden Ink hardware.
- No measured maintenance interval for periodic full refreshes or long-term image-quality data was established from these code sources.
- No concrete per-pixel mask implementation was verified in this research strand.

## Is there a credible software route to shorter physical refresh?

### Takeaway
An exact Waveshare community patch reports roughly halving the 7.3-inch refresh by changing the panel clock register. The report is promising, but reverse-engineered, unmerged, temperature dependent, and missing rigorous colour-quality and lifetime validation.

### Cited Findings
- PR #387, opened 29 March 2025 and still open, reports 7.3-inch refresh measurements of 12.932 seconds at PLL `0x03`, 10.075 at `0x04`, 8.798 at `0x05`, 7.832 at `0x06`, and 6.746 at `0x07`. The author calls out temperature dependence and describes the command knowledge as reverse engineered. — [PR report](https://github.com/waveshareteam/e-Paper/pull/387)
- The same report discusses hardware AUTO sequencing of power-on, display refresh, and power-off; the Python port uses command `0x17` with `0xA5` and waits for BUSY. It also changes several other initialization values, so adopting the entire patch would do considerably more than change one clock byte. — [Python source, lines 86–145](https://raw.githubusercontent.com/missionfloyd/e-Paper/spetra6-performance/RaspberryPi_JetsonNano/python/lib/waveshare_epd/epd7in3e.py)
- PR #389's author says the patch applies #387 to Python, batches parameter writes, speeds buffer packing, and adds partial update. No hardware testing narrative or colour-quality comparison appears in the retrieved conversation, and no reviews are listed. — [PR #389](https://github.com/waveshareteam/e-Paper/pull/389)

### Inferences
- The PLL change addresses the panel's driving cadence rather than merely host image preparation. It could shorten the distracting flashing, but does not remove full-screen flashing on a full update.
- A bounded experiment should compare baseline against one change at a time, with the actual artwork and text, ordinary room temperatures, and side-by-side colour/ghosting inspection. Bulk-swapping the community driver would obscure the cause of any regression.

### Gaps
- PR #387 does not specify timing instrumentation or exact start/end boundaries. Describe its numbers as author-reported refresh timings, not verified DRF-only/BUSY intervals or a promise for our unit.
- No controlled quality, longevity, or warranty conclusions can be drawn. Do not assert proven damage from this change, nor claim the speed is free of trade-offs.

## How does this fit the current Garden Ink driver?

### Takeaway
Garden Ink presently uses the slower clock byte found in the community comparison, and has no partial-window path. We did not modify the driver or touch hardware.

### Cited Findings
- `INIT_SEQUENCE` has `0x30=0x03` and `0x50=0x3F`; the driver is expressly adapted from Waveshare's HAT(E) `epd7in3e`. — [Local driver lines 1 and 12–18](../../display/gardenink/hardware.py)
- `show()` writes the full 192000-byte buffer, triggers one `0x12` refresh, times through BUSY completion, and powers off; `close()` puts the panel into deep sleep. It does not issue a separate blank-screen refresh. — [Local driver lines 84–105](../../display/gardenink/hardware.py)
- The native packed image is derived by rotating the portrait render 90 or 270 degrees. Window coordinates would therefore need the same transformation. — [Local palette packing](../../display/gardenink/palette.py)
- GxEPD2 separately tracks initialization, hibernation, and panel power; hibernation forces reinitialization. Its partial feature writes controller memory before refreshing the selected area, so state and sleep behavior deserve explicit integration tests. — [Source, lines 467–535](https://github.com/ZinggJM/GxEPD2/blob/master/src/epd7c/GxEPD2_730c_GDEP073E01.cpp)

### Inferences
- Existing driver refresh-duration logging gives us a useful baseline without changing waveform behavior.
- Safe integration would preserve persisted cooldown, sleep/power-off, and BUSY handling; add a capability-gated optional partial path; preserve full refresh recovery after uncertain updates; and validate on this actual panel before production adoption.
- Do not simply keep panel high voltage enabled to retain state. Distinguish controller RAM retention, panel power-off, and deep sleep when assessing a future prototype.

### Gaps
- Exact installed panel revision remains unverified by this strand. Software similarity is not component identity.
- Controller RAM persistence across our reset/deep-sleep cycle was not established by these sources; no claim that previous image retention in RAM is required or sufficient is made here.

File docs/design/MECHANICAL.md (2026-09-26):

# Counterframe mechanical guide

**Master:** `hardware/counterframe/counterframe.scad`.

**Construction guide:** `hardware/counterframe/BUILD_GUIDE.html` (illustrated HTML with adjacent render assets) and its Markdown `README.md`.

## Constraints carried forward

Structural parts are PLA only. No screws, threaded inserts, glue, metal ballast or elastomer feet are part of the delivered design. The screen is portrait and the object freestands on a kitchen counter. One external power cable goes directly to Pi PWR IN. A slim visible edge is achieved by tapering the back, not by forcing connectors into an unrealistically thin uniform housing.

The front bezel seats inactive glass borders without intentional preload. The carrier locates each PCB on four tapered-tip posts; the rear's annular collars prevent lift-off at the mounting-hole lands without wedging the PCB. Service face-down: with the cover removed, those collars no longer retain the boards axially.

## Delivered objects

| Category | Files |
|---|---|
| Structural prints | `stl/front.stl`, `carrier.stl`, `rear.stl`, `stand.stl` |
| Fit tests | `coupon_pins.stl`, `coupon_holes.stl`, `coupon_latch.stl`, `coupon_socket.stl` |
| Optional tool | `release_key.stl` |
| Non-printing references | Nine simplified glass/board/component/flex/wire/power-envelope meshes in `reference/` |
| Render tooling | `render.py`, `checks/export_render_meshes.py`, `checks/package.py` |
| Geometry checks | Intersection `.scad` files, `checks/run_collision.sh`, `checks/validate.py`, original `validation.json` |

All print dimensions are millimetres. Four structural prints, not one assembled STL; do not print the reference electronics or scale the parts to fit a smaller printer.

## Nominal geometry and unresolved assumptions

The body is 134 × 188 mm, maximum thickness 34 mm, visible perimeter depth 9 mm. The stand footprint is 142 × 108 mm; backward inclination 10 degrees. Those are source-CAD values, not measured dimensions of the assembled device.

The design assumes the **dedicated Waveshare HAT (E)** with its separate 45 × 21 mm adapter. It uses a matched **50 mm overall, 50-way FFC** between the boards, correct pitch and contact orientation to be checked on the actual kit. A large supplied ribbon cannot simply be creased into that route. The modelled bonded-tail and FFC bend radii are design assumptions, not vendor-certified bending limits. Keep stiffeners/bonded transitions straight.

The internal USB model assumes a slim straight micro-USB plug (9.6 × 14 × 5.6 mm moulding) and 3.4 mm jacket. The split saddle captures the flexible jacket, not a pulling load through the connector. Keep external slack. A right-angle or bulky plug is not a claimed fit.

The pin/hole coupons, glass pocket, PCB-height capture and cable-groove settings all depend on print calibration. Change all mating parts together. Do not press-fit glass or compensate for a tight assembly by pushing through the panel.

## Project wiring

Power down before changing connections. Physical pin numbers are not BCM numbers.

| HAT label | BCM/function | Physical Pi header pin |
|---|---|---:|
| BUSY | GPIO24 | 18 |
| RST | GPIO17 | 11 |
| DC | GPIO25 | 22 |
| CS | GPIO8 / SPI0 CE0 | 24 |
| SCLK | GPIO11 / SPI0 SCLK | 23 |
| DIN | GPIO10 / SPI0 MOSI | 19 |
| GND | Ground | 20 |
| VCC | 3.3 V in this working arrangement | 17 |

HAT switch: **0 = 4-line SPI**. External 5 V supply goes into **Pi PWR IN**, the right-hand micro-USB socket in the Pi board layout. Do not infer pin positions from the early, vertically drawn ASCII header or from cable colours in the CAD render. Read physical numbering/orientation on the actual board/vendor drawing.

This describes the confirmed project setup, not a universal voltage/pin guide for every Waveshare product. Use the dedicated (E) documentation linked in the construction guide and the current driver. GPIO8 chip select is owned by hardware SPI; GPIO18 is not a separate display-power connection in this eight-wire harness.

## Regeneration

Use a separate development output copy if you need to preserve the supplied final renders/STLs as a baseline:

```bash
cd hardware/counterframe
bash export.sh
python checks/export_render_meshes.py
python render.py
bash checks/run_collision.sh
python checks/validate.py
# After render.py has produced renders/internal_anchors.json:
python checks/package.py
```

`export.sh` needs OpenSCAD. Python rendering needs VTK, NumPy and Pillow; packaging the guide needs Mistune; mesh validation needs Trimesh. An off-screen OpenGL-capable environment may be needed for VTK. Optional workstation requirements are listed at the repository root. The existing rendered PNGs and offline guide require no regeneration to view.

`checks/run_collision.sh` intentionally continues after an empty CSG result; **its exit status alone is not proof of passing**. Run `checks/validate.py` afterwards and inspect the report. `checks/package.py` writes ZIPs beside the model folder; read it before running. Its input `internal_anchors.json` is generated by the internal render and was not part of the source tree.

## Qualification status

The original CAD report says engineering prototype, not physically fit-tested by its author. The project photograph shows a real white printed housing holding a working screen. That is useful evidence, but it does not establish exact model revision, internal retention tolerances, flex stress, safe temperature, tip/slip resistance or repeated latch life.

Record the actual printer/filament/layer settings, part version, modifications, cable length/contact orientation, plug dimensions and fitting feedback as the next mechanical task. The case is vented and not splash-proof; original material and placement warnings remain relevant. A local mesh or CSG pass does not certify the assembled appliance.

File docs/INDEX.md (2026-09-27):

# Documentation

| Document | Purpose |
|---|---|
| [Status and roadmap](STATUS_AND_BACKLOG.md) | Implemented behaviour, verification limits and planned improvements |
| [Spectra 6 refresh research](<../reports/Spectra 6 refresh improvements.md>) | Community timing and partial-area refresh experiments, evidence limits and proposed hardware trials |
| [Architecture](ARCHITECTURE.md) | Processes, modules, time/counting rules and persistence |
| [API contract](../display/docs/API_CONTRACT.md) | Required Open Observatory endpoints and filtering semantics |
| [After-dark carousel](design/NIGHT_MODE.md) | Switching thresholds, night comparisons and preview commands |
| [Visual specification](design/VISUAL_SPEC.md) | Layout, readability and artwork direction |
| [Readability rules and trial](design/READABILITY.md) | Provisional type sizes, labelled physical comparison and feedback protocol |
| [Mechanical guide](design/MECHANICAL.md) | CAD, wiring, printing and qualification limits |
| [Deployment](operations/DEPLOYMENT.md) | Fresh setup, upgrades and service diagnostics |
| [Local recovery](operations/LOCAL_RECOVERY.md) | Preserve and import artwork and device state |
| [Automatic artwork](operations/AUTOART.md) | Optional paid worker, limits and recovery |
| [Artwork workflow](artwork/WORKFLOW.md) | Workstation generation, review and approval |
| [Development](development/WORKFLOW.md) | Offline tests, previews and CAD checks |

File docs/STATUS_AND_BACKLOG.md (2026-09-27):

# Status and roadmap

## Current state

Garden Ink 2.1 provides an hourly, no-clock journal from a separate Open Observatory station. The project photograph shows this layout operating in a printed Counterframe enclosure. It establishes an assembled working device, not long-run service reliability or measured mechanical qualification.

| Area | Implemented | Remaining verification or limitation |
|---|---|---|
| Station client | Read-only bounded scan; today/hour aggregation; source/review filtering; partial totals | Recheck the API contract when upgrading the station |
| Display | HAT (E) driver, startup/manual pushed frames, on-the-hour scheduled reports, relevant-artwork redraws, persistent refresh guard, strong colour wash, controller sleep, portrait no-clock layout | Long-run reliability, live verification of artwork-triggered redraws and physical readability across lighting conditions |
| After dark | Sunset/quiet-bird/bat-or-owl entry; persisted sunrise latch; three illustrated hourly pages; filtered bat records and matched-window history | Verify a real dusk transition and physical night-page readability; historical zero windows lack detector-effort proof |
| Services | Display and optional artwork units; unit validation before installation | Confirm unattended startup/recovery on the deployed Pi |
| Pi artwork worker | Disabled by default; up to two workers; durable request reservations and uncertainty handling | Paid operation and low-memory behaviour require a separately authorised device trial |
| Workstation studio | Serial generation, recovery, review, approval and export | Existing paid collection must be imported; parallel generation is not implemented |
| Artwork | Original robin reference; 47 bundled illustrations; 53-species studio catalogue | Consistent reviewed collection, anatomy checks and thumbnail quality |
| Enclosure | OpenSCAD source, four structural prints, four fit coupons and a release key | Record print settings, exact revision, cable fit, retention, temperature and latch life |

## Improvement priorities

1. **Content quality:** clearer summaries while preserving acoustic identification and coverage semantics.
2. **Refresh methodology:** verify on-the-hour scheduling on the deployed Pi, retaining persisted hardware cooldown, DST and midnight correctness.
3. **Readability:** selected direct monochrome DejaVu Sans and three daily cards in physical trials; continue checking longer live labels and physical night-page readability.
4. **Power consumption:** measure the complete device. Controller sleep does not suspend the Pi; no battery-life claim is established.
5. **Art style:** complete a consistent robin-reference collection, with human review of anatomy and species markings.

## Maintenance work

- Reconcile deployed source and existing artwork before replacing either; preserve uncertain paid attempts and approvals.
- Verify installed services and cooldown after upgrades.
- Improve studio export errors to distinguish missing, unapproved and uncertain images.
- Check Pillow forward compatibility without changing request fingerprints.
- If studio concurrency is added, use one coordinator/state writer with bounded requests and explicit uncertain-request recovery.
- Develop an explicit-file, state-preserving deployment helper before automating upgrades.

Offline tests cannot certify hardware operation, live-station compatibility, paid API access or physical fit.

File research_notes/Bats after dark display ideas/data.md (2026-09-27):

# Bat display data feasibility

## What does the existing system support?

### Takeaway
The source already supports ultrasonic bat-event records, history, solar moments and microphone coverage. Garden Ink itself is currently bird-only. These are source-code findings and recorded project reports, not a fresh check of the deployed station.

### Cited Findings
- The reference Open Observatory uses an AudioMoth USB microphone captured at 384 kHz, with the 48 kHz audible stream derived from the same frames. USB describes the microphone connection; `alsa` is the software capture source, not a separate audible-only microphone. The source chooses `AlsaSource` and routes native-rate windows to the ultrasonic detector. [README](/home/simon/Documents/OpenObservatory/README.md:3), [source choice](/home/simon/Documents/OpenObservatory/src/open_observatory/station.py:487), [native detector](/home/simon/Documents/OpenObservatory/src/open_observatory/station.py:809).
- `ultrasonic-pass-v1` emits `taxonomic_group="bat"`, label `bat pass`, rank `None`, pulse/frequency statistics and a possible feeding-buzz flag. Its frequency hints explicitly are not species identifications. It refuses a native rate below its minimum, and optional night scheduling can return no detections while capture continues. [detector](/home/simon/Documents/OpenObservatory/src/open_observatory/detectors/ultrasonic.py:299), [event fields](/home/simon/Documents/OpenObservatory/src/open_observatory/detectors/ultrasonic.py:499).
- `GET /api/v1/detections?group=bat` supports UTC since/until, optional detector plugin filtering and up to 500 records/page. Payloads contain start/end, duration, peak frequency, source identity, detector/model version, withdrawal and latest review/effective name. Detailed individual records additionally expose native pulse/buzz statistics. [list endpoint](/home/simon/Documents/OpenObservatory/src/open_observatory/api/app.py:1608), [detail](/home/simon/Documents/OpenObservatory/src/open_observatory/api/app.py:1821), [payload](/home/simon/Documents/OpenObservatory/src/open_observatory/api/app.py:3032).
- The analytics API has night/day series, local-hour matrices, per-day solar moments, captured seconds, missing-day/status reporting and daylight/night spans. It reads roll-ups rebuilt by an hourly worker. ADR-079 records a Pi deployment/backfill, but this inspection did not verify that deployment today. [endpoints](/home/simon/Documents/OpenObservatory/src/open_observatory/api/app.py:2158), [ADR](/home/simon/Documents/OpenObservatory/docs/architecture/adr/ADR-079%20-%20Analytics%20section.md:34).
- Garden Ink requests `group=bird` and its reducer rejects non-birds and non-species ranks, so bat passes need a separate reduction policy, not just new artwork. Its existing today/trailing-hour logic and refresh cooldown must remain intact. [client](/home/simon/Documents/garden-ink/display/gardenink/client.py:100), [reducer](/home/simon/Documents/garden-ink/display/gardenink/model.py:31), [architecture](/home/simon/Documents/garden-ink/docs/ARCHITECTURE.md).

### Inferences
- Lowest-risk content candidates are a chart of qualifying acoustic detection records, first/last detection, peak detection period, and measured call-frequency bands. Any frequency-band panel should avoid converting those bands into asserted species.
- A possible feeding-buzz story is feasible as a later, carefully labelled candidate event with an educational explanation. A buzz flag alone cannot prove a feeding attempt succeeded, prey was caught or even the classifier was correct.
- “Minutes with at least one qualifying bat detection” is derivable from deduplicated raw timestamps, but is a new defined metric, not an existing active-minutes endpoint. Define start-minute versus interval-overlap binning explicitly, and never relabel it as minutes an individual bat spent in the garden.

### Gaps
- No live query was made: current capture rate, active detector, deployment revision, usable prior nights, coordinates and review quality remain unverified.
- No environmental weather input/API was found in the source search; temperature hits were CPU temperature. Weather correlations would need another source and time-aligned history, not the computer's temperature.

## Can tonight be compared honestly with the previous seven nights?

### Takeaway
Yes as a designed extension, preferably one current-night curve against a seven-night median/range, aligned to elapsed time after sunset. Existing aggregates are useful groundwork but do not directly implement Garden Ink's review policy or exact sunset-aligned windows.

### Cited Findings
- Analytics `grain=night` is **noon to noon**, keyed to the evening date; it is not sunset to sunrise. `/history`'s older `last-night` resolves to a fixed 20:00–08:00 window. Neither should be silently presented as astronomical darkness. [series](/home/simon/Documents/OpenObservatory/src/open_observatory/analytics.py:771), [history resolver](/home/simon/Documents/OpenObservatory/src/open_observatory/history.py:234).
- Solar code computes sunrise/sunset and civil dawn/dusk when coordinates are supplied. Analytics returns solar moments with hourly data. [solar calculation](/home/simon/Documents/OpenObservatory/src/open_observatory/schedule.py:80), [hours endpoint](/home/simon/Documents/OpenObservatory/src/open_observatory/api/app.py:2198).
- A critical policy mismatch: group-level analytics and history timelines intentionally retain withdrawn/rejected records as historical detection events. The named analytics table excludes withdrawn/rejected records and applies corrected names, but still does not expose all Garden Ink confidence/review eligibility choices. Bat labels are frequency bands in that table. [module policy](/home/simon/Documents/OpenObservatory/src/open_observatory/analytics.py:13), [builder predicates](/home/simon/Documents/OpenObservatory/src/open_observatory/analytics.py:285), [history endpoint](/home/simon/Documents/OpenObservatory/src/open_observatory/api/app.py:2118).
- Roll-ups carry freshness and missing-day information; days touched by a recent review are scheduled for rebuilding, and older stale days rotate through rebuilds. Withdrawals can therefore lag until rebuilding. [rebuild scheduling](/home/simon/Documents/OpenObservatory/src/open_observatory/analytics.py:538), [stale policy](/home/simon/Documents/OpenObservatory/src/open_observatory/analytics.py:53).
- Existing local-hour roll-ups merge the autumn repeated hour into one two-hour wall-clock cell and make the spring skipped cell empty. They therefore cannot exactly recover all UTC elapsed-since-sunset bins on DST transition nights. [hour windows](/home/simon/Documents/OpenObservatory/src/open_observatory/analytics.py:108).
- Garden Ink already has bounded backward pagination, per-window completeness and explicit lower-bound counts, preserving corrections through re-reads. It does not currently query historical capture coverage. [API contract](/home/simon/Documents/garden-ink/display/docs/API_CONTRACT.md).

### Inferences
- Define each report night by its evening date, extending across local midnight. Compute sunset/sunrise separately for the correct local dates, then use UTC for elapsed durations and comparisons. Preserve bird “today” at local midnight independently.
- Compare tonight only through the report's last completed matching bin with the same elapsed period after sunset on each eligible prior night. Do not compare tonight's partial total with completed-night totals. Use “3 of 7 comparable nights available” when history is insufficient; never manufacture seven nights.
- Good 480×800 concept: one bold current-night line or bar series, a restrained previous-seven-night median/range and one headline comparison. Gaps are absent/hatched, not zeros; the future part of tonight stays blank. The comparison can use detection records per bin, with a capture strip beneath and a clear metric label.
- Raw records (or a new station-side filtered aggregate) are needed to preserve Garden Ink source/review/withdrawal semantics and exact alignment. Query with min_score=0, then apply a bat-specific policy so human confirmation is not discarded by the original score. A bird confidence threshold should not silently become a bat threshold: this detector's score formula is different.
- Baselines should not cross known microphone moves, gain/threshold/schedule/model changes without disclosure. Existing model/plugin IDs help detect some changes, but do not certify stable microphone placement or all detector settings.

### Gaps
- No verified endpoint exposes a ready-made seven-night sunset-aligned, Garden Ink-filtered comparison.
- Read-only source inspection did not establish complete historical detector-settings epochs or a cheap review-compliant aggregate at the desired resolution. A raw seven-night scan must retain bounded pagination and honest partial results rather than assuming it is inexpensive.

## What does coverage really prove, and which concepts need least extra data?

### Takeaway
Microphone capture coverage is implemented, including stream sample rates and gaps. That is not proof all captured ultrasound was analysed, so a zero line should say “no qualifying bat detections” rather than “no bats”.

### Cited Findings
- `/history` coverage includes microphone seconds, stream intervals with sample rates, gaps, suspect-stream counts and pauses. It caps stream duration with recorded frames and merges overlapping intervals. The aggregate live seconds include all ALSA sample rates; consumers can inspect stream sample rates separately. [coverage implementation](/home/simon/Documents/OpenObservatory/src/open_observatory/history.py:695), [stream spans](/home/simon/Documents/OpenObservatory/src/open_observatory/history.py:735), [response](/home/simon/Documents/OpenObservatory/src/open_observatory/history.py:858).
- Detection coverage is a separate SLO based on analysed versus dropped windows. Current station status exposes detector snapshots, but the inspected historical/analytics coverage paths do not persist per-bin ultrasonic analysis effort. [SLO](/home/simon/Documents/OpenObservatory/src/open_observatory/slo.py:239), [status snapshots](/home/simon/Documents/OpenObservatory/src/open_observatory/station.py:2156).
- Ultrasonic health reveals current gating, while the schedule may be always or night and has configurable twilight margins. [health](/home/simon/Documents/OpenObservatory/src/open_observatory/detectors/ultrasonic.py:569), [schedule state](/home/simon/Documents/OpenObservatory/src/open_observatory/schedule.py:234), [defaults](/home/simon/Documents/OpenObservatory/src/open_observatory/config.py:609).
- E-ink is hourly, 480×800 portrait, with no free-standing or implied live clock. Historical intervals, retained report dates and explicit cached/offline status are established conventions. [visual specification](/home/simon/Documents/garden-ink/docs/design/VISUAL_SPEC.md).

### Inferences
- Distinguish three notions: complete API scan, microphone recording coverage at adequate native rate, and ultrasonic detector analysis effort. Neither complete data retrieval nor generic 100% microphone coverage proves bat detector availability throughout the night.
- Derive eligible recording intervals from live ALSA streams at a suitable native rate rather than directly using aggregate microphone seconds when streams vary. Mark uncertain detector effort instead of silently normalising by generic capture hours.
- Data-light alternatives: (1) a “night so far” strip with first/last detection, (2) a seven-night barcode of minutes containing detections, (3) “when the garden usually wakes after sunset” based on qualifying first-detection offsets, or (4) last completed night's summary while a new night has insufficient data. These are design suggestions, not delivered features.
- A small illustrated educational note can keep the screen interesting on quiet/unavailable nights without pretending there is live activity. Use static researched content separate from observation claims.

### Gaps
- Current indoor readability after dark and whether additional ambient lighting is needed were not physically tested. No hardware driver, scheduler, service or station was changed.

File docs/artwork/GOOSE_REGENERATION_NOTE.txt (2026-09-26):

Anatomy requirement: exactly TWO legs and exactly TWO webbed feet in total, one foot per leg. Draw a single Canada goose standing naturally on flat ground in a clear right-facing side view. Make the two legs distinct and anatomically connected to the body. No third leg, duplicate foot, extra limb, reflection or vertical ground stroke resembling another leg. Preserve the original robin reference's ink-and-wash style.

Example species-specific correction. Import/check the existing species.json before applying it to preserve request fingerprints.

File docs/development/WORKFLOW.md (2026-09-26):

# Development

Use a root workstation virtual environment, Python 3.9+ and Pillow. DejaVu fonts, including the italic faces in `fonts-dejavu-extra`, must be installed separately. Pi GPIO dependencies are installed by `display/install.sh`, not the workstation requirements.

```bash
python3 -m venv .venv
.venv/bin/python -m pip install -r requirements-dev.txt
make test PYTHON=.venv/bin/python
make preview PYTHON=.venv/bin/python
make verify PYTHON=.venv/bin/python
```

`tools/test_all.py` runs display, auto-art, studio and project suites in separate processes. Tests use local mock HTTP servers and mocked paid responses. Credential environment variables are removed before subprocesses start. Logs go under ignored `local/test-results/`.

`make preview` renders labelled sample data at 480 × 800 into `local/previews/no-clock.png`, without GPIO, station access or paid requests. Review at actual size. For layout changes include empty/quiet, long names, unknown art, midnight, DST, offline/paused and partial-window cases. `make verify` runs the same offline tests and preview; it is not a live-device certification.

## Services

Use the scripts' `print-unit` and `verify` commands on a configured temporary installation to validate generated units with `systemd-analyze verify`. Do not install or restart live services as a workstation check. Stop timeouts allow in-flight scans, refreshes and paid requests to finish.

## Artwork and persistence

Use the exact original robin reference. Preserve existing paid output and fingerprints through [local recovery](../operations/LOCAL_RECOVERY.md). No paid requests belong in tests or routine previews. Do not reset cooldowns, spending counters or uncertain attempts to make checks pass.

## CAD

`make cad-check` checks the nine printable meshes using the optional `requirements-cad.txt` dependencies. Regeneration and collision checks are described in the [mechanical guide](../design/MECHANICAL.md). CAD passes do not establish physical fit or safety.

## Publishing

Keep secrets, site configuration, observation logs, artwork ledgers, private backups and generated local output out of commits. Review staged files and image metadata before pushing. Use a GitHub no-reply commit email. CI runs the offline tests and preview only.

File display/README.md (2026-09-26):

# Garden Ink display

The Pi application for the [Open Observatory](https://github.com/simonjgreen/OpenObservatory) e-ink companion. A reachable Open Observatory station supplies observations; this application provides the alternative hourly display interface.

See the [project README](../README.md), [deployment guide](../docs/operations/DEPLOYMENT.md) and [API contract](docs/API_CONTRACT.md).

```bash
./run.sh --demo --preview     # invented sample data; no network or GPIO
./run.sh --preview            # station data to PNG; no GPIO
./run.sh --check              # station diagnostics; no GPIO
./run.sh --once               # physical edition, respecting saved cooldown
./service.sh status
./service.sh diagnose
```

The layout is 480 × 800 portrait for the Waveshare HAT (E), with a date and historical report times. The refresh interval is approximately 3,600 seconds. Today starts at local midnight; the last hour is 60 elapsed minutes.

Missing-art generation is disabled by default. Read [automatic artwork](../docs/operations/AUTOART.md) before enabling paid requests. Custom artwork takes precedence over generated cache and bundled images.

`test.sh` runs the display suite. Use `make test` at the repository root for all current suites. `upgrade.sh` is a legacy v1-to-v2 migration helper, not a general deployment command.

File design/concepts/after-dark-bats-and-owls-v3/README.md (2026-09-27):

# Bats and owls carousel — revised visual direction

Generated 27 September 2026 with the built-in image generation tool.

## User decisions

- Restore the earlier flying-bat visual alongside the owl artwork.
- Keep an owl illustration on both graph pages and a large owl portrait on the field-journal page.
- Remove caveat text from the pages: focus on what was heard, recorded activity and historical report times.
- Do not repeatedly explain bat species-identification limitations. Bat presence and acoustic activity are the point of this display.
- Keep count labels accurate and compact: these concepts use detection-record counts, not individual animal or individual-call counts. This replaces the earlier activity-minute concept for this visual iteration.

## Files

1. 01-night-rhythm.png — bat illustration and total above hourly bat detection chart, owl occurrence lane and illustrated owl panel.
2. 02-seven-nights.png — bat illustration above recent-night detection comparisons, owl occurrence column and illustrated owl panel.
3. 03-night-field-journal.png — large owl portrait with supporting bat illustration, total and hourly chart.

These are AI-generated design concepts using invented sample data, not live station results or tested renderer output. Provenance is kept here and in the accompanying message rather than on the display pages, as requested. Source bat counts are 34,72,51,27 (184 total), baseline hourly medians 27,50,36,27, seven-night totals119,134,98,146,158,126,184. Owl sample: three qualifying detections, last at9.18pm BST, all in the2–3hour bin. The report window is6.45pm–10.45pm BST. These counts are new illustrative fixtures, not a numerical conversion from the earlier minute-based sample.

The previous owl pages were edit targets. The earlier flying-bat illustration was a user-requested compositing input, not a chained style reference. The original art_studio/reference/robin.png remains the sole illustration style reference. Existing curated images and generation state were not changed.

## Prompt set

### 01-night-rhythm

Use case: ui-mockup editing / compositing. Revise this Garden Ink after-dark carousel page based on user's latest direction: restore the beloved BAT ILLUSTRATION alongside the OWL PICTURE, and REMOVE ALL CAVEAT / DISCLAIMER TEXT from the screen. It must feel like a beautiful natural-history journal that celebrates what was heard.
INPUT ROLES: Image1 = page EDIT TARGET, preserve overall editorial identity and owl art. Image2 = ORIGINAL robin, the sole illustration style reference. Image3 = existing bat field-journal page, a SUPPORTING COMPOSITING INPUT: reuse its existing flying-bat illustration as an artwork insert, not as a style reference for generating new art. Copy that bat's visual, cleanly extracted against white, with intact full wings. Do not reproduce any text from image3. The original robin remains the only style reference; don't chain generated artwork styles.
White portrait3:5 screen only, approx960x1600; no bezel, scene, perspective, shadow, gradients or rounded cards. Fine black natural-history hatching, warm ochre brown wash in animals, restrained blue charts. Elegant serif headings, italic 'After dark', crisp legible sans-serif supporting labels. Flat white paper.
KEEP common header: 'OPEN OBSERVATORY', large 'The garden', italic 'After dark', 'Night of 27 September 2026', then fine rule and 'Report covers 6.45pm–10.45pm BST'. Report time is historical, do not add live clock.
DELETE completely: 'DEMO', 'invented observations', 'Concept preview', 'sample data', 'not your garden', 'Bat species not determined', 'Acoustic identification', all 'not a count of animals' or 'detections are not animals' explanations and similar caveats. No disclaimers anywhere. We label these mockups as sample data externally in the accompanying message, NOT inside the artwork.
Change chart metric from activity-minutes to RECORD COUNTS with label 'Bat detections'. Use exactly these fictional bat detection counts: four hourly bins34,72,51,27, total184. Median comparison27,50,36,27. Seven-night four-hour totals119,134,98,146,158,126,184 for21–27Sep. These are detection records, so use 'detections' labels, never claim animal counts, sightings, visits or individual calls. No bat species labels needed.
Owl remains Tawny owl / Strix aluco, 'Last heard at 9.18pm BST', '3 detections in this report'. Three records all in hour2–3 after sunset. Keep owl illustrated on all pages, and owl hero on page3. Keep both animals beautifully drawn and large enough to enjoy. Screen copy should be minimal and affirmative. Footer ONLY 'Night edition · [page] / 3'.
PAGE1, footer 'Night edition · 1 / 3'.
Recompose upper content to put a beautiful medium flying BAT illustration, about150logical pixels wide, opposite the heading 'THE NIGHT’S RHYTHM' and a clear large stat '184' / 'bat detections'. Bat should be recognisable and detailed, not a tiny silhouette. Keep owl distinct below, don't blend animals.
Central chart: four blue bars34,72,51,27; dashed black median27,50,36,27, y ticks0,20,40,60,80. X labels0–1,1–2,2–3,3–4, caption 'Hours after sunset'. Legend 'Tonight' and 'Previous 7 nights · median'. Separate thin 'Owls heard' lane with diamond under2–3 only. Chart title/measure 'Bat detections'. Charts must plot correct scale, no minute units anywhere.
Lower quarter a prominent illustrated owl panel: full perched owl at left, 'OWLS TONIGHT', 'Tawny owl', italic'Strix aluco', 'Last heard at 9.18pm BST', '3 detections in this report' at right. Preserve original owl visual. Use freed disclaimer space to breathe. No redundant oversized takeaway.

### 02-seven-nights
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

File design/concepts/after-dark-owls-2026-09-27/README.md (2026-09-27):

# After-dark carousel with owl artwork

Three visual concepts generated with the built-in image generation tool on 27 September 2026. The approved direction is an hourly three-page carousel: two bat graph pages with a persistent illustrated owl panel, and an owl-led field-journal page when an owl has been heard that night. These files are concept previews, not implementation or hardware validation.

## Pages

- 01-night-rhythm-with-owl.png: bat activity profile and separate owl occurrence lane; illustrated Owls tonight panel.
- 02-seven-nights-with-owl.png: comparable four-hour bat activity windows over seven dates, separate owl occurrence column; illustrated Owls tonight panel.
- 03-owl-field-journal.png: large tawny owl illustration with historical acoustic-identification details and supporting bat activity chart.

All observation data and times are invented and visibly labelled. The same sample evening is used throughout: four bat activity-minute bins of 12, 23, 17, 8; three qualifying tawny-owl records in the 2–3 hour bin, last at 9.18pm BST. Activity minutes and detection records are different units, neither is an animal count. Seven-night owl marks appear on 23, 25 and 27 September. Historical baselines and monitoring completeness are assumed for these sample concepts only.

The previous concepts were edit targets for typography/layout, not chained illustration references. The original art_studio/reference/robin.png remains the sole art style reference. Owl illustrations are AI-generated concept artwork, not approved replacements for the existing curated collection. No station, services, application code, credentials or paid-generation ledgers were accessed or changed for this render task.

The images were visually inspected for layout, text and observation semantics. Production work still needs deterministic charts, shared approved owl artwork, actual 480×800 rendering/palette checks and physical readability verification.

## Prompt set

### 01-night-rhythm-with-owl

Edit target: design/concepts/after-dark-2026-09-27/01-night-rhythm.png
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

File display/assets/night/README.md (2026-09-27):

# Night artwork

`bat.png` was extracted on 27 September 2026 from the existing approved concept
`design/concepts/after-dark-2026-09-27/03-bat-field-journal.png`, using the built-in
imagegen editing tool. It was not generated through the paid artwork service or
an API key. The source was an edit target, not a new style reference. The PNG's
alpha channel is preserved; the renderer composites it onto white before the
existing native-colour ink/wash treatment. This is an illustration, not a station
species identification. Existing owl artwork uses the usual curated-first lookup.

The extraction was visually checked for a single complete bat with the original
pose, two wings, ears and hind feet, and no surrounding page text. It still needs
the same human artwork review as the rest of the collection; this is not a claim
of biological validation or panel testing.

Final prompt (built-in tool; no CLI):
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

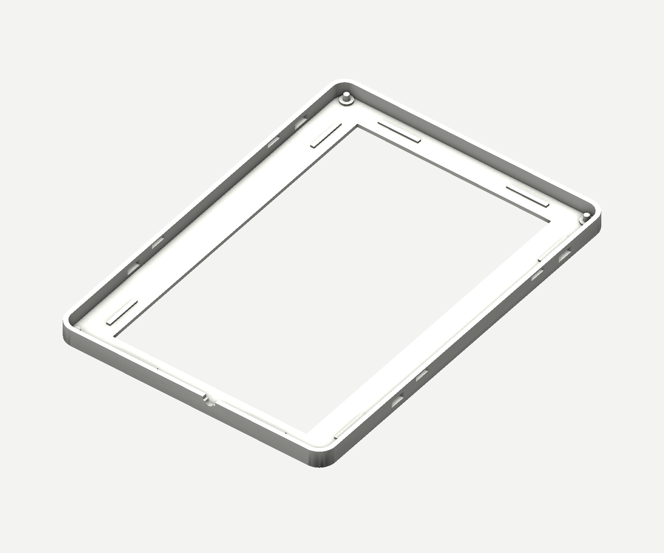
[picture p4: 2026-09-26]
hardware/counterframe/renders/front_part.png

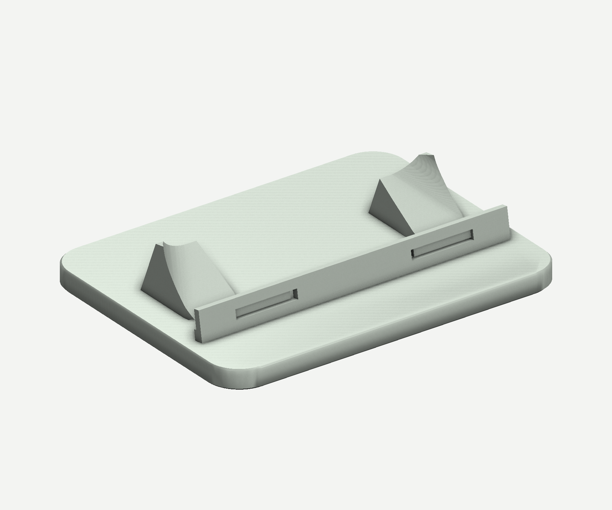
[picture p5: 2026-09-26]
hardware/counterframe/renders/stand_part.png

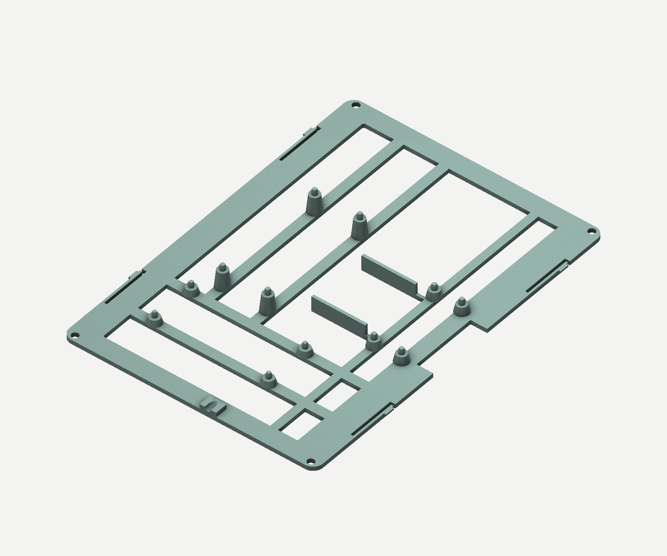
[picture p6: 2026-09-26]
hardware/counterframe/renders/carrier_part.png

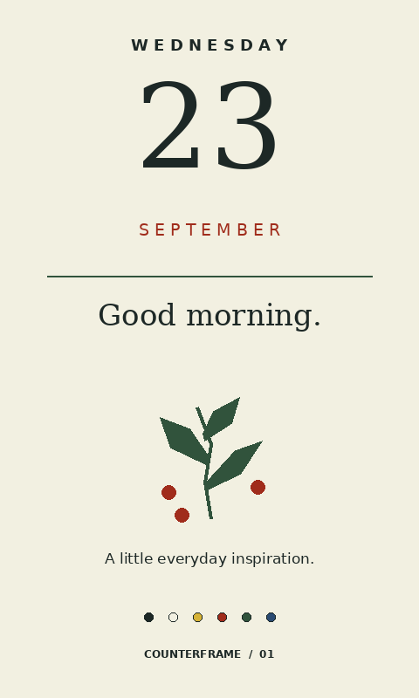
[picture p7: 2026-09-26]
hardware/counterframe/renders/screen_artwork.png

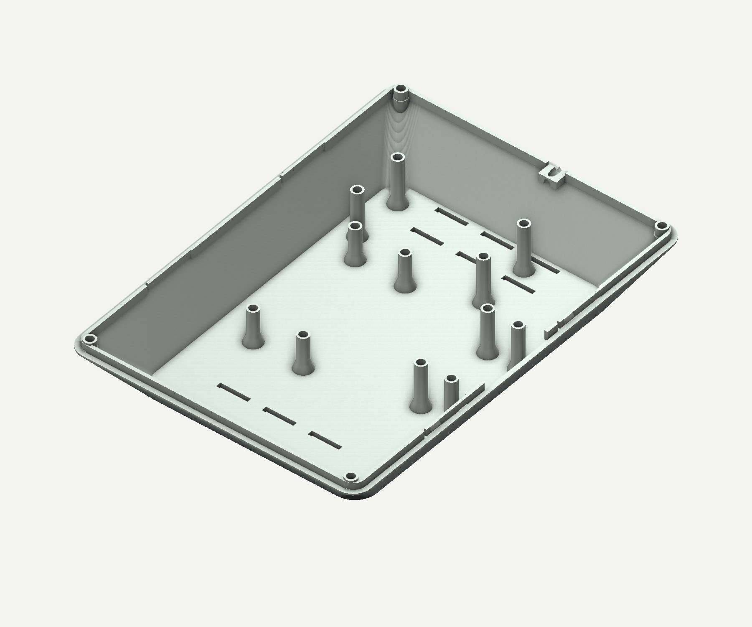
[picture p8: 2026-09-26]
hardware/counterframe/renders/rear_part.png

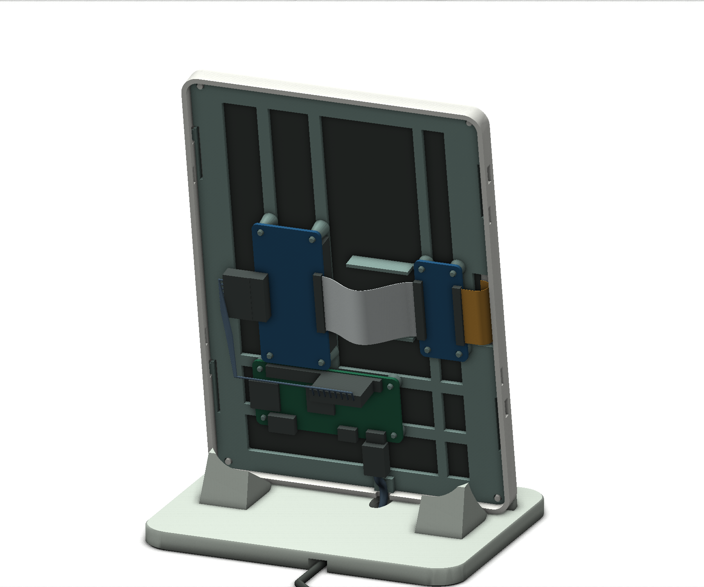
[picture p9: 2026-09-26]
hardware/counterframe/renders/internal.png

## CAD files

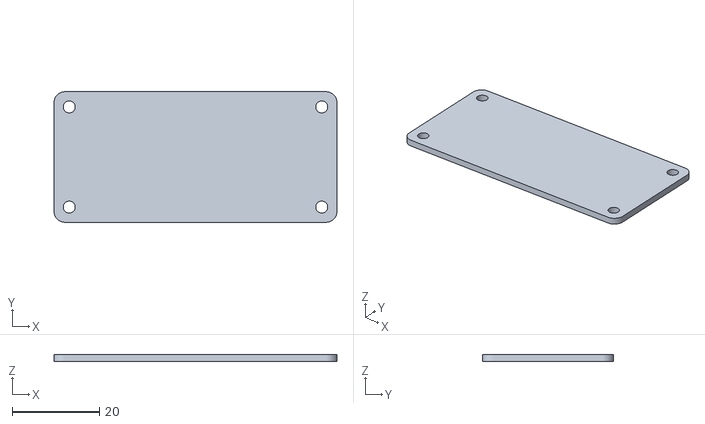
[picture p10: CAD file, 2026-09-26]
hardware/counterframe/reference/pi_pcb.stl
65.0 x 30.0 x 1.60

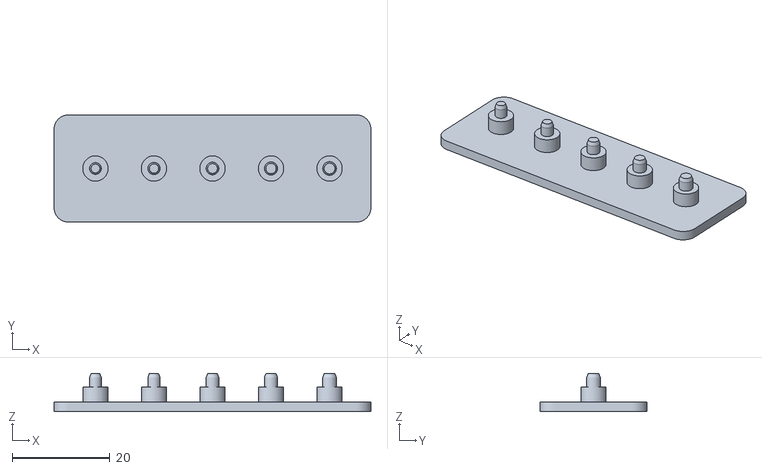
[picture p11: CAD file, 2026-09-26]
hardware/counterframe/stl/coupon_pins.stl
65.0 x 22.0 x 7.80

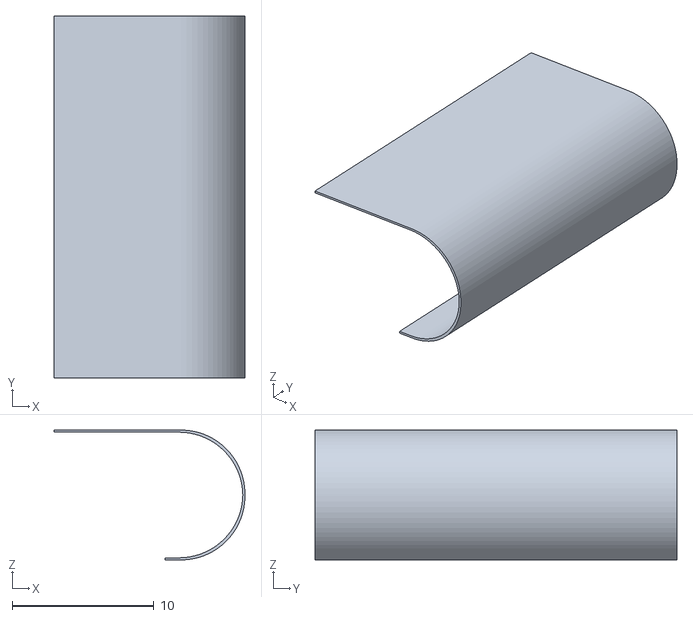
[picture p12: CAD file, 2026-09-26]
hardware/counterframe/reference/fpc.stl
13.5 x 25.5 x 9.15

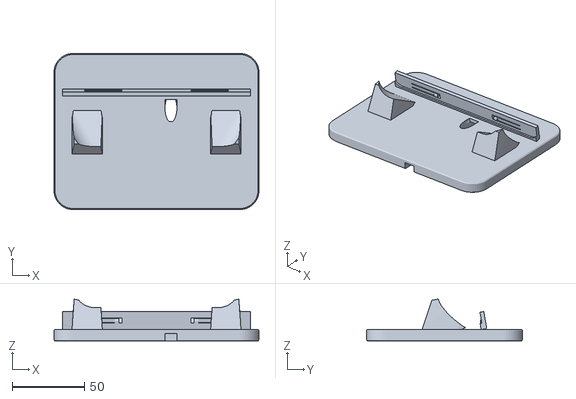
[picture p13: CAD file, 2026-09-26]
hardware/counterframe/stl/stand.stl
142.0 x 108.0 x 29.0

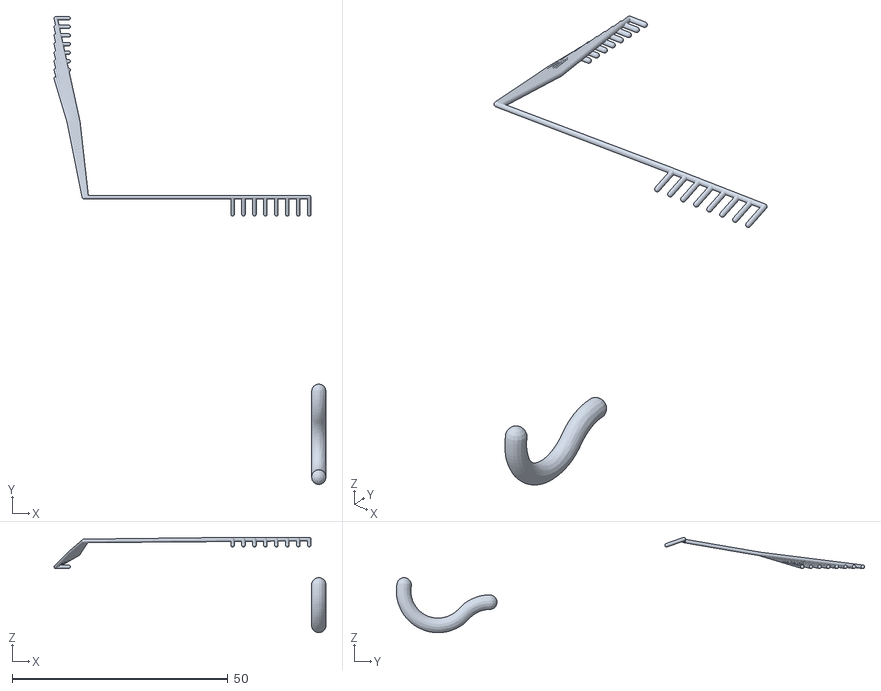
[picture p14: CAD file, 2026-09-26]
hardware/counterframe/reference/wires.stl
63.1 x 108.6 x 22.1

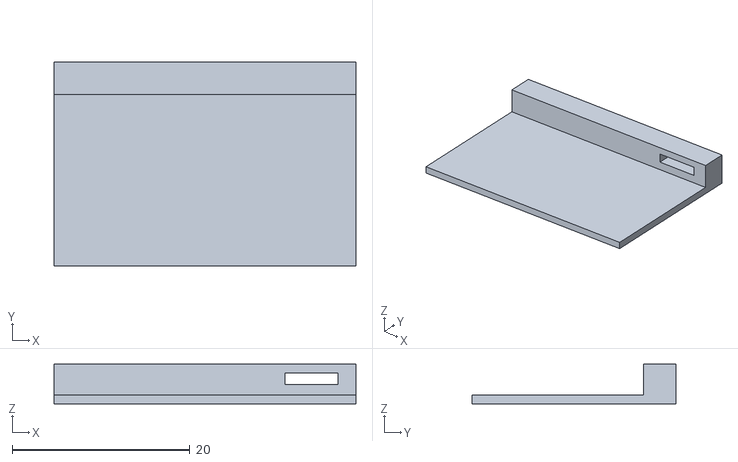
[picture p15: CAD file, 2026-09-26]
hardware/counterframe/stl/coupon_socket.stl
34.0 x 23.0 x 4.50

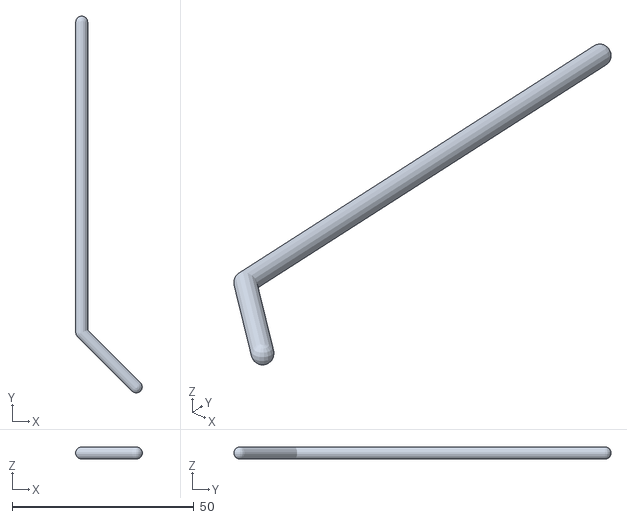
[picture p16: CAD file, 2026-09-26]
hardware/counterframe/reference/power_external.stl
18.3 x 103.7 x 3.33

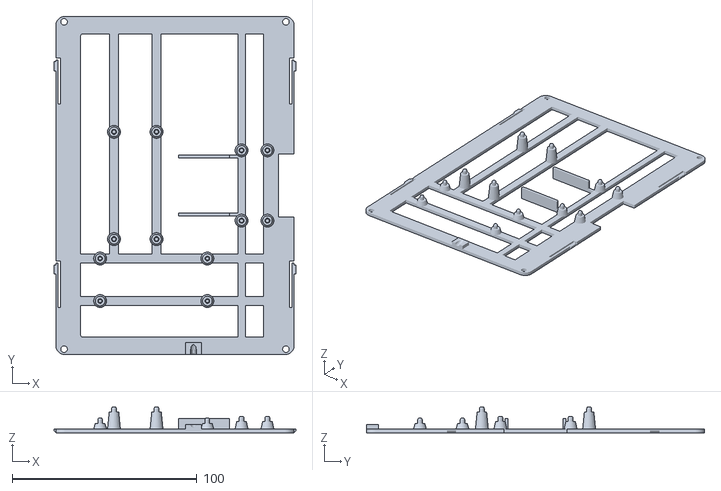
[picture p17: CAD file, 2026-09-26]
hardware/counterframe/stl/carrier.stl
130.9 x 183.0 x 14.0

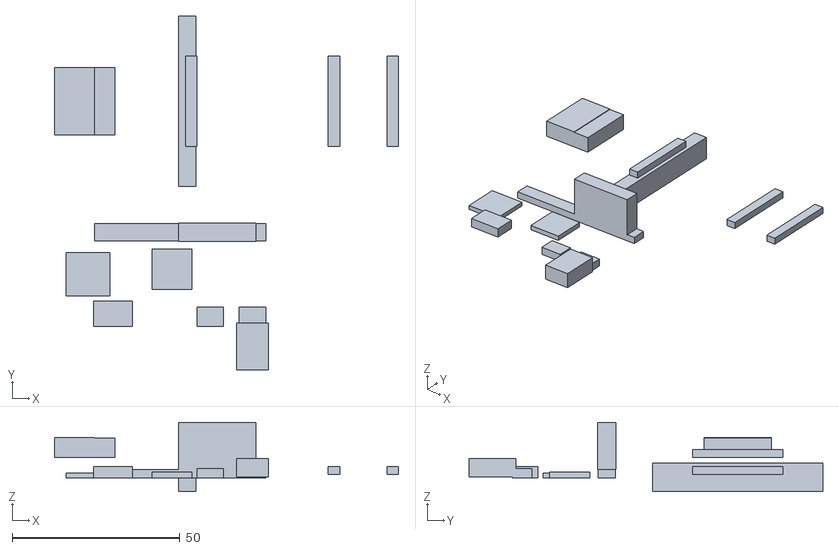
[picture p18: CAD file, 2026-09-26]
hardware/counterframe/reference/components.stl
102.5 x 105.4 x 20.6

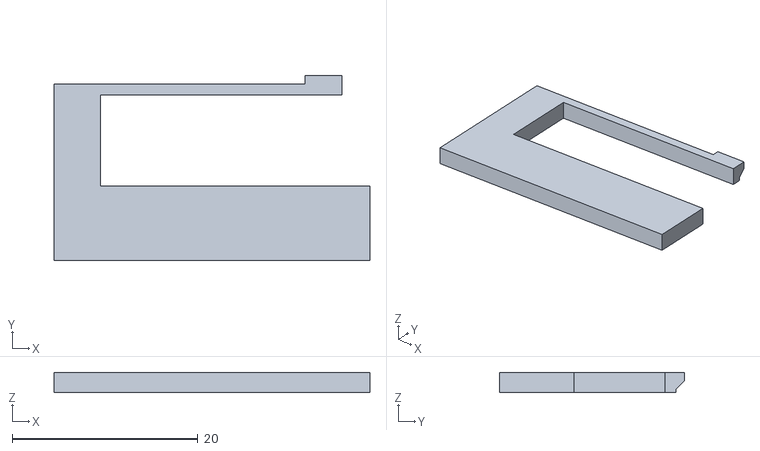
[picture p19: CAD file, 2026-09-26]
hardware/counterframe/stl/coupon_latch.stl
34.0 x 19.9 x 2.20

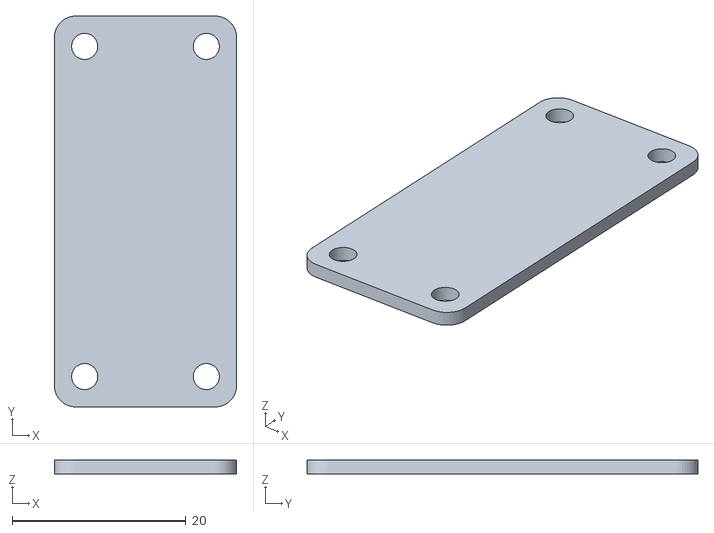
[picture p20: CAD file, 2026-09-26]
hardware/counterframe/reference/adapter_pcb.stl
21.0 x 45.0 x 1.60

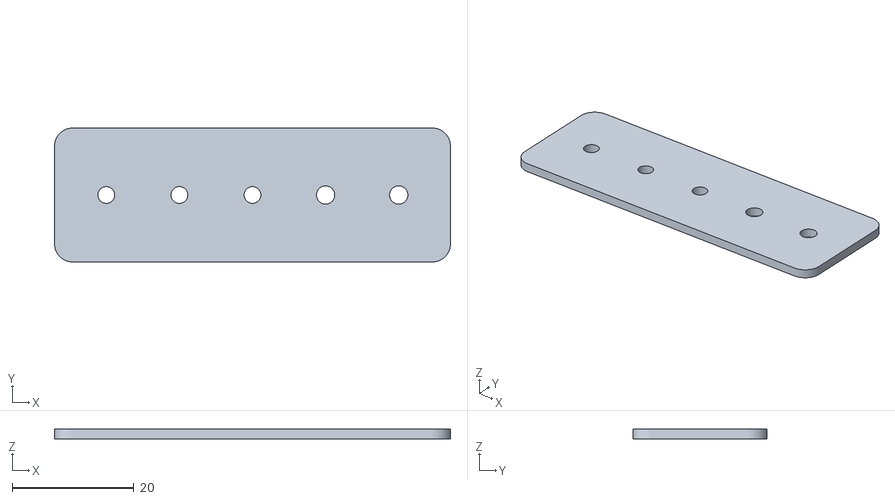
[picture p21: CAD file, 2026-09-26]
hardware/counterframe/stl/coupon_holes.stl
65.0 x 22.0 x 1.60

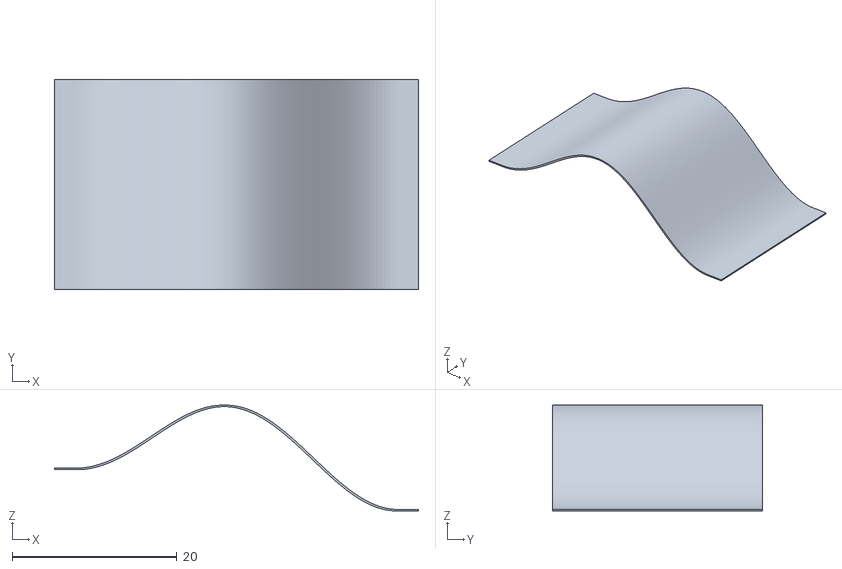
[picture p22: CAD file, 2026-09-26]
hardware/counterframe/reference/ffc.stl
44.2 x 25.5 x 12.8

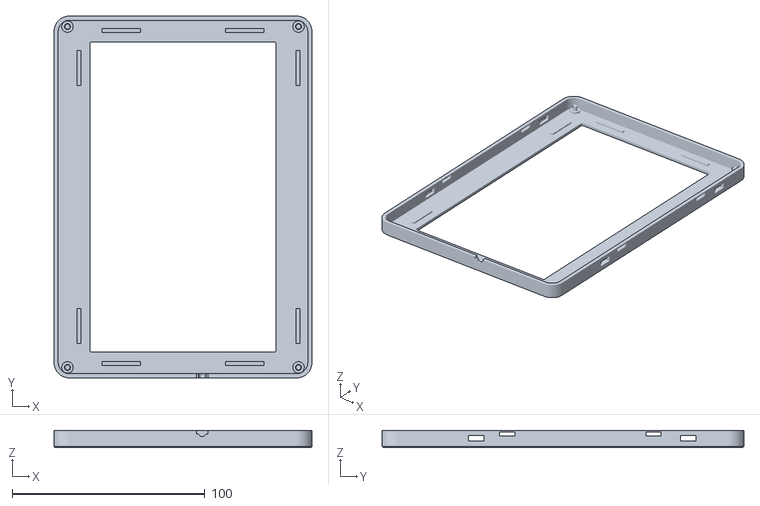
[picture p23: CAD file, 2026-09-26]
hardware/counterframe/stl/front.stl
134.0 x 188.0 x 9.00

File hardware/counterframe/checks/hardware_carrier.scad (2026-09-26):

include <../counterframe.scad>
intersection(){ hardware_native(); carrier_native(); }

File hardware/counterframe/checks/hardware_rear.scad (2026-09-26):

include <../counterframe.scad>
intersection(){ hardware_native(); rear_native(); }

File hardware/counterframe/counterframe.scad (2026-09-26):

/*
COUNTERFRAME / 7.3 E6 / v1.0 engineering prototype
Generated design, 2026. CC0-1.0 for this code and generated enclosure meshes.
Manufacturer drawings and trademarks are not included in that dedication.
Units: mm. Four structural parts, no screws, glue, inserts, magnets or elastomers.
Read README.md before printing: the glass and FPC are NOT press-fit parts.

Hardware baseline, checked 2026-09-23:
- Waveshare 7.3inch e-Paper HAT (E), 6 colours, NOT (F)/(G).
  Glass 170.2 x 111.2 x 0.91; active 160 x 96; active offsets 5.1 / 4.7.
  Dedicated HAT 65 x 30.5, 58 x 23 hole pitch, 3 mm holes.
  FPC adapter 45 x 21, 38 x 14 hole pitch, 3 mm holes.
- Pi Zero envelope 65 x 30; 58 x 23 holes, diameter 2.75.
- Component HEIGHTS, cable jacket and glass thickness require measurement.
- FFC routing model: 50 mm OVERALL, 50-way, matching kit contact orientation.
  A short matching replacement FFC is required if the kit cable is longer.

Source drawing URLs and assumptions in README.md.
Coordinates looking INSIDE FROM THE REAR: X right, Y up, Z toward the rear.
Front is Z=0. Bonded panel FPC exits +X (left edge when looking at the screen).
part='assembly' is a visual assembly, NOT a single printable STL.
Use the four part selectors to export the manufacturing STLs.
*/

/* [Output] */
part = "assembly"; // [assembly,exploded,front,carrier,rear,stand,coupon_pins,coupon_holes,coupon_latch,coupon_socket,release_key,section,hardware,ribbon,wires]
show_hardware = true;
show_cables = true;
quality = 48;
$fn = quality;

/* [Measured hardware - verify before print] */
panel_w = 111.2;
panel_h = 170.2;
panel_t = 0.91;
active_w = 96;
active_h = 160;
// Difference between panel and active-area centres in portrait orientation.
panel_dx = 2.9;
panel_xy_clear = 0.30; // PER SIDE, not total
panel_z_clear = 0.15;  // capture clearance; never clamp glass by closing case
pcb_t = 1.60;
pi_peg_d = 2.50;
hat_peg_d = 2.70;
pcb_capture_clear = 0.15;
cable_d = 3.40;
cable_grip = 0.10;    // diametral squeeze on USB jacket only; measure first
fpc_radius = 4.50;    // design assumption, NOT a manufacturer-certified limit

/* [Case] */
case_w = 134;
case_h = 188;
edge_depth = 9;
case_depth = 34;
wall = 2.2;
front_t = 1.8;
corner_r = 8;
carrier_t = 2.2;
fit = 0.30;
lean = 10;
base_w = 142;
base_d = 108;
base_t = 8;
base_cy = -26;
bottom_lift = 10;

/* [Hidden] */
eps=0.025;
carrier_z=front_t+panel_t+panel_z_clear;
carrier_top=carrier_z+carrier_t;
pi_pos=[-44,-66];
pi_size=[65,30];
pi_z=carrier_top+3;
hat_pos=[-37,-32.5];
hat_size=[30.5,65];
hat_z=carrier_top+9; // preserves stock underside female GPIO connector
adapter_pos=[32.5,-22.5];
adapter_size=[21,45];
adapter_z=carrier_top+4;
pi_holes=[for(x=[3.5,61.5],y=[3.5,26.5]) [pi_pos[0]+x,pi_pos[1]+y]];
hat_holes=[for(x=[4,27],y=[3.5,61.5]) [hat_pos[0]+x,hat_pos[1]+y]];
adapter_holes=[for(x=[3.5,17.5],y=[3.5,41.5]) [adapter_pos[0]+x,adapter_pos[1]+y]];
carrier_fix=[for(x=[-60,60],y=[-88.5,88.5]) [x,y]];
usb_x=pi_pos[0]+54;
usb_z=7.4;
frame_inner_x=case_w/2-wall;
carrier_half=case_w/2-wall-fit;
back_w=104;
back_h=148;
// Smooth S-bend of USB jacket, R8 design radius; the split saddle follows it.
// This is a cable envelope assumption, not a cable manufacturer's rating.
usb_R=8;
usb_start_y=-79.5;
usb_start_z=12.8;
usb_a=acos(1-(usb_start_z-usb_z)/(2*usb_R));
usb_mid_y=usb_start_y-usb_R*sin(usb_a);
usb_mid_z=usb_start_z-usb_R*(1-cos(usb_a));
usb_internal_points=concat(
    [for(a=[0:usb_a/8:usb_a]) [usb_x,usb_start_y-usb_R*sin(a),usb_start_z-usb_R*(1-cos(a))]],
    [for(a=[usb_a:-usb_a/8:0]) [usb_x,usb_mid_y-usb_R*(sin(usb_a)-sin(a)),
                                      usb_mid_z-usb_R*(cos(a)-cos(usb_a))]]);
usb_exit_y=usb_start_y-2*usb_R*sin(usb_a);
// R8 sweep turns the cable rearwards under the stand BEFORE it reaches the worktop.
usb_exit_points=[for(a=[0:5:90+lean]) [usb_x,usb_exit_y-usb_R*sin(a),usb_z+usb_R*(1-cos(a))]];
usb_path=concat(usb_internal_points,usb_exit_points);
usb_last=usb_exit_points[len(usb_exit_points)-1];
usb_world_y=cos(90+lean)*(usb_last[1]+case_h/2)-sin(90+lean)*usb_last[2];
usb_world_z=bottom_lift+sin(90+lean)*(usb_last[1]+case_h/2)+cos(90+lean)*usb_last[2];

assert(panel_w>active_w && panel_h>active_h,"Panel must exceed active area");
assert(panel_z_clear>=0.05,"Do not force-clamp the glass");
assert(case_depth>=33,"Default GPIO lead boots require 33+ mm; recheck envelopes");
assert(case_w>=134,"FPC loop needs the default right-side clearance");
assert(pi_peg_d<2.75 && hat_peg_d<3,"Locators must clear PCB holes, not wedge them");
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

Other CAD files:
hardware/counterframe/reference/glass.stl
hardware/counterframe/stl/release_key.stl
hardware/counterframe/reference/hat_pcb.stl
hardware/counterframe/stl/rear.stl
hardware/counterframe/checks/carrier_rear.scad
hardware/counterframe/checks/front_carrier.scad
hardware/counterframe/checks/front_rear.scad
hardware/counterframe/checks/render_adapter_pcb.scad
hardware/counterframe/checks/render_components.scad
hardware/counterframe/checks/render_ffc.scad
hardware/counterframe/checks/render_fpc.scad
hardware/counterframe/checks/render_glass.scad
hardware/counterframe/checks/render_hat_pcb.scad
hardware/counterframe/checks/render_pi_pcb.scad
hardware/counterframe/checks/render_power_external.scad
hardware/counterframe/checks/render_wires.scad
hardware/counterframe/checks/ribbon_carrier.scad
hardware/counterframe/checks/ribbon_front.scad
hardware/counterframe/checks/ribbon_rear.scad
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

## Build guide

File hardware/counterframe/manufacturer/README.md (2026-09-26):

# Manufacturer references

`SOURCES.json` lists the dimensional references used for the CAD. Manufacturer PDF/JPG files are not bundled. Fetch and verify the applicable drawing before a mechanical revision.

Manufacturer materials retain their owners’ terms. The CAD’s CC0 designation does not relicense vendor drawings; approximate reference meshes are not manufacturer STEP models or endorsements.

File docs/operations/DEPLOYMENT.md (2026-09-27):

# Deployment

`display/` is the deployable Pi application. It depends on a reachable [Open Observatory](https://github.com/simonjgreen/OpenObservatory) station. CAD and workstation tools do not need to be installed on the Pi.

## Existing installations

Before changing a running device, compare its source with this checkout and make a private backup. Stop the services cleanly, allowing in-flight requests to finish:

```bash
cd ~/garden_ink
./service.sh stop
# If the optional worker is installed:
./autoart-service.sh stop
cd ~
umask 077
tar -czf "garden_ink-private-$(date +%Y%m%d-%H%M%S).tar.gz" garden_ink
```

Keep the backup outside Git. It may contain credentials, observations and paid artwork. An active SQLite database must be backed up coherently with its WAL; a stopped-service copy avoids a partial ledger snapshot.

Preserve `config.json`, `autoart.json`, token paths, `.secrets/`, custom PNGs/manifests/catalogue and all `state/`. See [local recovery](LOCAL_RECOVERY.md). Review and dry-run source synchronisation before copying files. Avoid broad deletion or copying workstation state onto the device. `upgrade.sh` is a legacy v1-to-v2 migration, not a general updater.

After copying only reviewed program files, validate the installation and generated units before restarting. Never clear `state/display.json` or the artwork ledger to force a refresh or retry.

## Fresh installation

Copy `display/` into `~/garden_ink`, then run as the normal Pi user:

```bash
cd ~/garden_ink
./install.sh http://YOUR-STATION:8080
./run.sh --check
./run.sh --once
./service.sh install
```

The installer uses OS packages and may require a reboot/re-login for SPI and group membership. The workstation virtual environment is not a transferable Pi runtime. Configure your own station URL, timezone and optional token locally; these are not committed.

`--check` reads the station without GPIO. `--preview` reads the station and writes an image without GPIO or paid work. `--demo --preview` uses invented data and no network. `--once` drives the panel and honours the persisted cooldown. Do not run unrelated Waveshare demos alongside the service; they do not share its advisory hardware lock.

## Push an update

From the installed application folder, run:

```bash
./service.sh refresh
```

This cleanly restarts the display service and requests a fresh frame. Installation, startup and ordinary service restart now request a frame too, followed by the regular hourly schedule. The request skips hourly timing but retains at least 180 seconds since the last saved panel attempt (successful or failed); it waits before fetching current data when necessary. This is the minimum interval recommended in the [HAT (E) manual](https://www.waveshare.com/wiki/7.3inch_e-Paper_HAT_%28E%29_Manual). No cooldown file or counter is cleared. Use `./service.sh logs` to confirm `Panel asleep` after the refresh; the refresh command returns when the service starts, not when the pigment has settled.

With the service already stopped, `./run.sh --refresh-now` performs one pushed update and exits. It uses the same persisted minimum and advisory hardware lock. `--once` continues to use the ordinary saved interval; preview/check modes cannot be combined with `--refresh-now`.

## Service diagnostics

```bash
./service.sh print-unit
./service.sh verify
./service.sh install
./service.sh status
./service.sh diagnose
./service.sh logs
```

The installer validates the generated unit with `systemd-analyze verify`. `WorkingDirectory` uses an unquoted path; `ExecStart` argument quoting has different rules. After its startup frame, a healthy service with the default hourly cadence waits for the next local `HH:00` before fetching a report. Fetching and physical refresh take time, and the saved panel cooldown can delay the physical attempt further. Controller sleep does not mean the Pi is suspended.

## Optional paid artwork

Read [automatic artwork](AUTOART.md) before running `./autoart.sh enable` and `./autoart-service.sh install`. This is a separate service and spending decision. Validate it on the device with an explicit request budget before unattended use. Offline tests do not submit paid requests.

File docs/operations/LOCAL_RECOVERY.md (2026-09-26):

# Preserve and recover local state

The repository contains application source and bundled artwork. Machine-local configuration, credentials, paid generations and approval/spending state belong to the installation and are excluded from Git.

| Location | Preserve |
|---|---|
| Workstation studio | `output/` including raw/prepared/archive files and `state.json`; exact `species.json`, `STYLE_BRIEF.txt`, `reference/robin.png`; finished art ZIP |
| Pi | Deployed source, configuration, tokens and `.secrets/` privately; custom artwork/manifests; refresh/snapshot state; coherent auto-art ledger and image directories |
| Printing workstation | Revised CAD, slicer project, print settings, cable dimensions and measured fit notes |

## Import an existing studio

Stop all studio generation/review/export processes. From the project root:

```bash
.venv/bin/python tools/import_workstation_art.py /path/to/existing/art_studio
# Inspect the plan, then explicitly apply it:
.venv/bin/python tools/import_workstation_art.py /path/to/existing/art_studio --apply
cd art_studio
PYTHON=../.venv/bin/python bash art.sh list
PYTHON=../.venv/bin/python bash art.sh generate --set all --plan
```

The importer selects output, catalogue, style/reference and finished art ZIP. It excludes credentials, virtual environments and old code. Existing destination material is backed up under gitignored `local/import-backups/`. Both studio locks are checked; nested directories and symlinks are refused. Wait for running work rather than deleting a lock.

Import request fields together with images: species-specific notes, model settings and reference bytes determine fingerprints. Preserve approvals, uncertain states and rejected attempts. List/plan do not make API calls. A timeout may have incurred a charge; inspect saved raw files and use explicit recovery before considering a new paid request.

## Pi recovery

Make a complete private backup with services stopped as described in [deployment](DEPLOYMENT.md). A separate comparison copy can live under gitignored `local/pi-snapshot/`. Exclude `.secrets/`, token files, environment files and any custom credential paths from copies intended for sharing. Review configuration and logs for site details as well.

Gitignore is not encryption. Do not upload private snapshots. Compare source separately and install reviewed artwork through its importer. Keep `state/autoart/jobs.sqlite3` and any required WAL/SHM files coherent; it contains request reservations, spending and recovery history. Keep `state/display.json` so upgrades preserve the physical cooldown.

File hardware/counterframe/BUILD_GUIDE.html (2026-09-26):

COUNTERFRAME / 7.3 E6 / V1.0

# A quiet place for a changing screen.

Portrait countertop enclosure for the Pi Zero and Waveshare Spectra 6 (E).

4 structural PLA parts0 screws142 × 108 × 195 mm assembled

Engineering prototype; an assembled device is shown in the project README, but detailed fit qualification remains outstanding. Confirm the exact (E) hardware, a matched 50 mm FFC and the slim USB plug before the full print.

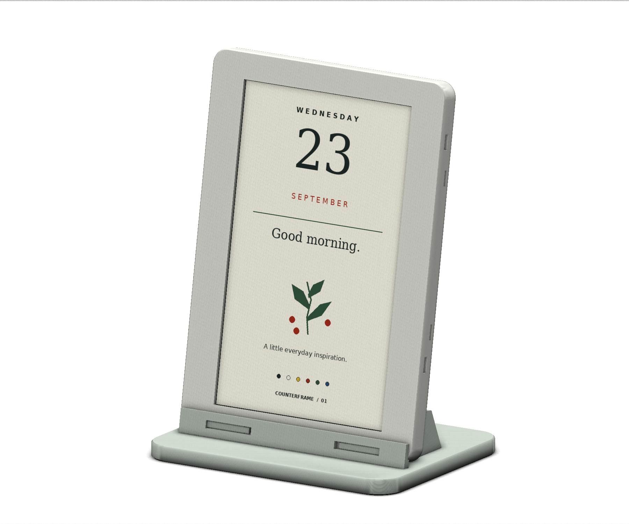
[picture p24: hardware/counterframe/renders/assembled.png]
Assembled CAD render. Illustrative content on the display.


Assembled CAD render. Illustrative content on the display.

The four structural prints. Individual STL geometry in print orientation.

The four structural prints. Individual STL geometry in print orientation.

Open-rear layout, including the short replacement FFC and single USB power lead.

Open-rear layout, including the short replacement FFC and single USB power lead.

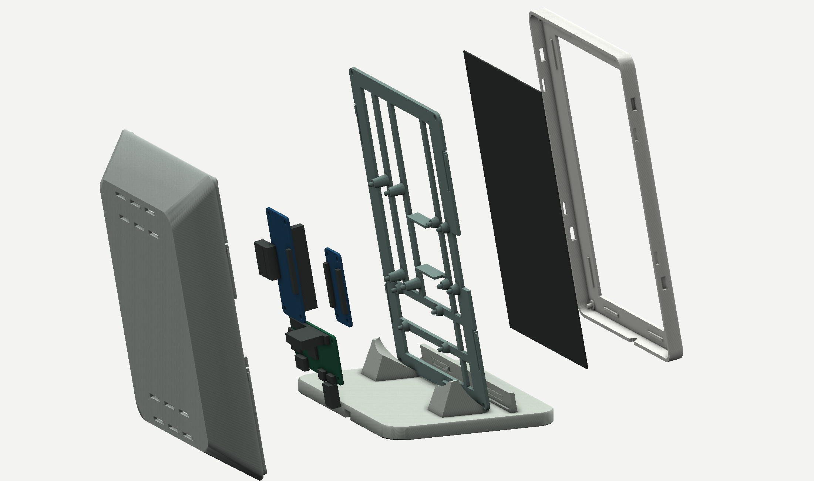
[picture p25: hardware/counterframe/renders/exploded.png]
Exploded geometry view. Cables omitted for clarity.


Exploded geometry view. Cables omitted for clarity.

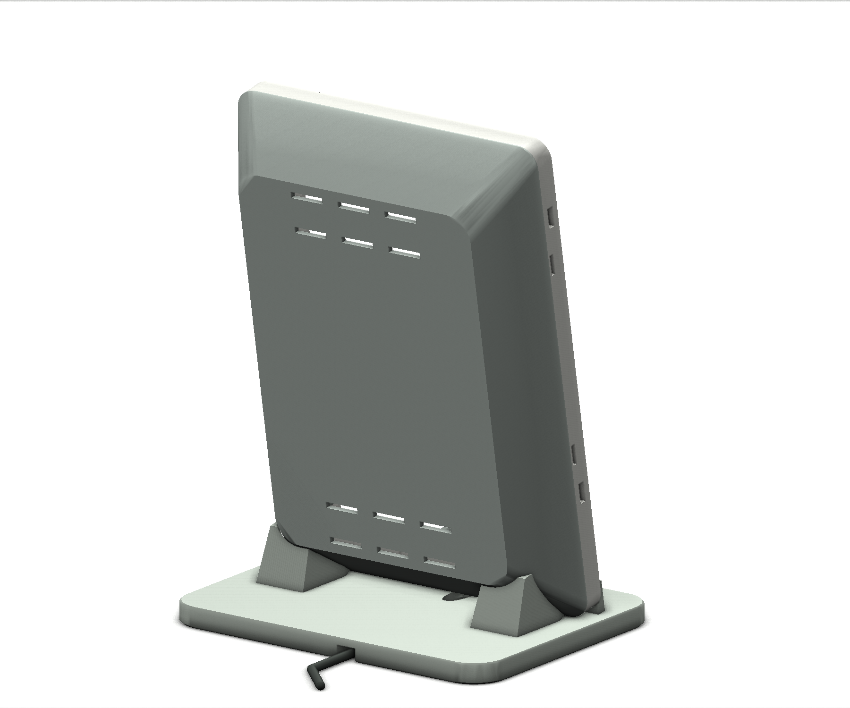
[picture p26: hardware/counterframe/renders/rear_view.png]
Tapered rear cover and cable exit behind the stand.


Tapered rear cover and cable exit behind the stand.

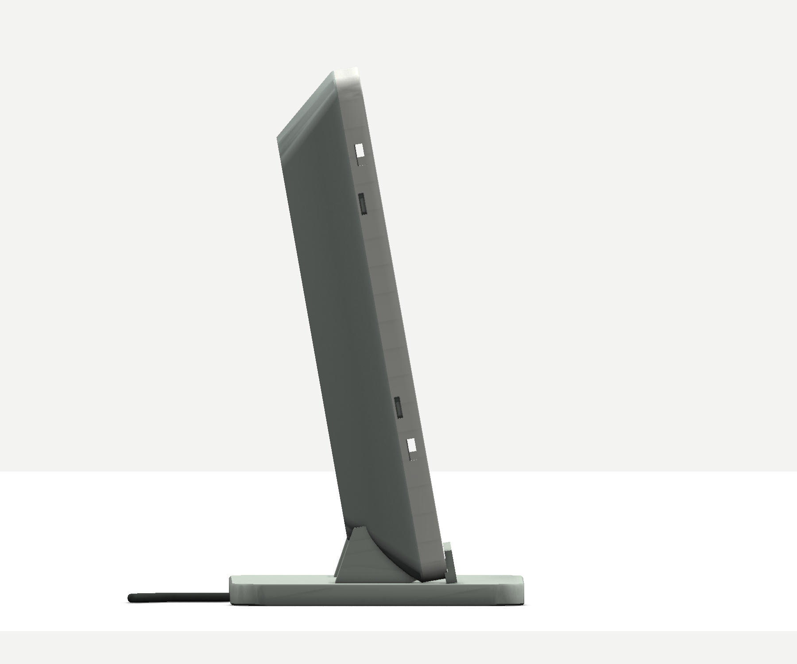
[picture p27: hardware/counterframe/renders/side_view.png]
The 10-degree lean and thin visible perimeter, with space behind for connectors.


The 10-degree lean and thin visible perimeter, with space behind for connectors.

# Counterframe / 7.3 E6

Portrait countertop enclosure · four structural PLA prints · no screws

Version 1.0 engineering prototype, 23 September 2026. Designed in OpenSCAD and exported to individual manufacturing STLs. The render images are produced from the same geometry, not concept illustrations of a different object.

Detailed physical fit qualification remains outstanding. Published board outlines and mounting-hole positions have been checked; component heights, cable dimensions, bend suitability, print tolerances and real countertop stability still require first-article verification. Read the compatibility table before printing. Do not force the display or its bonded flex to fit.

## Design at a glance

The front is a softly rounded picture frame, with a 9 mm-deep perimeter and a rear housing that tapers to a smaller back face. The maximum enclosure depth is 34 mm. A separate low plinth holds the screen 10 degrees back from vertical. Boards are mounted beside one another rather than stacking the HAT on the Pi.

Item | Nominal CAD dimension
Front body | 134 × 188 mm
Maximum body thickness | 34 mm
Visible straight perimeter depth | 9 mm
Stand footprint | 142 × 108 mm
Main plinth thickness | 8 mm
Assembled height | Approximately 195 mm
Display opening | 96.8 × 160.8 mm, portrait
Image area | 96 × 160 mm, portrait
Shell wall / front face | 2.2 / 1.8 mm
Backward inclination | 10°

The bezel centres the visible image, not the raw glass outline. The glass is offset by 2.9 mm relative to the image centre because the original panel's inactive borders are unequal. The wider side border also makes room for the bonded flex to return behind the display.

## Files

- counterframe.scad: editable master model; no external CAD library required.
- stl/front.stl, carrier.stl, rear.stl, stand.stl: print one of each.
- stl/release_key.stl: optional small PLA tool for pressing the release tabs.
- stl/coupon_pins.stl, coupon_holes.stl: peg-fit samples.
- stl/coupon_latch.stl, coupon_socket.stl: small snap-fit practice pieces.
- renders/: assembled, rear, side, internal, exploded and individual-part views.
- BUILD_GUIDE.html: illustrated offline guide; open in a browser.
- validation.json: mesh and nominal geometry check results, with their limitations.
- export.sh: reproduces the manufacturing STLs with the OpenSCAD CLI.
- render.py and checks/export_render_meshes.py: optional renderer; requires Python, VTK, NumPy and Pillow in addition to OpenSCAD. reference/ contains non-printing, approximate electronics and cable envelopes used by it.

All manufacturing STLs are in millimetres, already oriented for printing. Do not merge them into a single print, scale them to fit a bed, or print the electronics reference meshes. The assembly and exploded selectors are for inspection, not a single printable object.

## Hardware compatibility: verify these first

This is specifically based on Waveshare 7.3inch e-Paper HAT (E), E Ink Spectra 6, with its separate small FPC adapter and dedicated blue driver HAT. It is not a claimed fit for the seven-colour (F), the four-colour (G), a generic e-Paper driver board, or a PhotoPainter board. [S1–S4]

Hardware | Published outline / holes used | What still needs measuring
Display glass | 170.2 × 111.2 mm; active 160 × 96; model thickness 0.91 mm | Actual thickness, back-side features and allowable flex-bending region
Dedicated (E) HAT | 65 × 30.5 mm; 58 × 23 hole pitch; Ø3 mm holes | Underside header and top-side connector/switch heights
Small adapter | 45 × 21 mm; 38 × 14 hole pitch; Ø3 mm holes | Socket orientation, housing heights and any underside parts
Raspberry Pi Zero | 65 × 30 mm; 58 × 23 hole pitch; Ø2.75 mm holes | Your board revision, populated components and GPIO connector boots

The Pi mounting pattern is taken from the official Pi Zero drawing. The component keep-out is a conservative approximation, not a manufacturer STEP model. A Zero 2 W may share the mounting outline, but this package does not certify every component of every Zero-family revision. Check your actual unit. [S5]

### Specific cable and connector assumptions

1. One slim, straight micro-USB plug into the Pi's PWR IN port. The modelled moulded body is 9.6 mm wide × 14 mm long × 5.6 mm thick; the cable jacket is Ø3.4 mm. A bulky boot, ferrite bead or right-angle connector is not an assumed fit. This does not add a USB-C panel socket or a USB extension inside the case.
2. 50 mm overall-length, 50-way FFC between the adapter and HAT, with the correct pitch and contact-side arrangement for the kit. The modelled path is 50 mm including the seated ends. This is a short interconnect, not an attempt to fold a long kit cable into the case. The actual supplied cable length has not been established; obtain a matching short replacement when necessary. Measure yours; do not stretch a shorter cable to this route or compress a longer one into a tight crease. Preserve the manufacturer's contact orientation.
3. An eight-wire SPI/power lead connects the remote HAT to the Pi GPIO. The model permits female jumper housings extending 14 mm above the Pi header plastic. Follow the Waveshare pinout; the simplified wire colours and positions in the render are not a wiring diagram. No second external power supply is designed into the enclosure.
4. The short bonded panel tail is taken as 24 mm long × 25.5 mm wide from the drawing. Its modelled return has a 4.5 mm bend radius. The separate 50 mm FFC follows one smooth arch with approximately 6.7 mm minimum modelled radius. These are design assumptions, not manufacturer-approved minimum bend radii. Reject the route if it would bend a stiffener, IC, bonded transition, or unsuitable portion of the actual tail. [S2, S6]

## How the retention works

### Front bezel and glass

The glass rests on its inactive front border inside broad lateral guides. It is captured between the bezel and the skeletal carrier with 0.15 mm nominal axial clearance and 0.30 mm clearance per side. There is no intended spring preload, press fit, conical peg contact or adhesive on the glass. The carrier must click home without squeezing or bowing it. The nominal backside air gap also separates the carrier crossbars from the glass.

### Internal carrier and boards

The carrier locates on four tapered bezel pins and locks into four side windows with long, in-plane flexure tabs. Each PCB sits on four tapered-tip locating posts. Their parallel locating portions are Ø2.50 mm for the Pi and Ø2.70 mm for the HAT and adapter. The taper is a lead-in, not a wedge driven into the PCB hole.

The rear cover has twelve integral annular retaining collars aligned with those posts. When the lid is fitted, these capture the mounting-hole lands from above with 0.15 mm nominal clearance. Central bores in the collars clear the peg tips. This separates lateral location from axial retention and avoids relying on friction in a PCB hole. The rear cover has separate hard stops over the four carrier fixings, relieved for the front locator tips.

The boards are intentionally not retained against lifting while the cover is removed. Assemble and service with the frame lying face-down, not standing vertically with loose boards hanging on pegs.

### Rear cover and stand

Four independent rear-cover snap tabs engage their own side windows. The front and carrier clips use different positions, so servicing the lid does not require releasing the glass carrier.

The stand has a fitted angled cradle, two rear buttresses and two detent leaves that engage recesses below the image. It is a separate part so its mass can be concentrated low down. Print it solid PLA: no metal ballast or rubber feet are required by the design.

PLA feet are not a substitute for rubber grip. The wide base is intended to resist tipping during modest movement, but the actual unit may slide on a polished or wet counter. This design has not been bump-, pull- or drop-tested. Lift it by the base rather than by the display bezel.

## Cable routing

Viewed from the open rear, the Pi is at the bottom, the driver HAT is above it on the left, and the small adapter is on the right.

- The display's short bonded flex exits the right side in this rear view, rounds back inside the side pocket and enters the adapter's outer socket. Seen from the front, this is the display's left edge.
- The white 50 mm FFC follows a single broad arch between the adapter and HAT. Its centreline travels monotonically from one socket to the other, so it has no crossing folds. It bends through its thickness, without an edgewise fold or twist. The carrier has fences beside this lane and the lid's retaining columns are outside the modelled route.
- SPI wires run left from the Pi below the lower HAT mounting posts, then up the left-hand side into the HAT's eight-pin connector. Do not pull them diagonally across the lid's collar positions.
- USB power enters the Pi directly, follows a shaped jacket saddle at the lower edge, and sweeps rearwards through the stand's open underside channel. The nominal jacket path uses 8 mm-radius bends. Only this flexible jacket is lightly captured; the plug and PCB connector must not carry a cable tug.

The saddle follows the curved USB path and is split between the carrier and lid. A plug does not have to be pushed through a tiny printed hole. Its default groove is 0.10 mm smaller than the measured jacket diameter; set cable_grip=0 initially when the jacket's compressibility is unknown. Use the same setting to regenerate both carrier and rear cover. Check that the jacket is held without flattening, cutting or levering the plug.

The cable guidance is not an industrial strain-relief rating. Leave slack behind the stand so a moved appliance or pulled lead does not load the micro-USB connector or topple the frame.

## Printing

Suggested starting point for a calibrated 0.4 mm-nozzle FDM printer:

Part | Orientation in supplied STL | Starting settings / supports
Front | Visible face on bed | 0.16–0.20 mm layers, 4 perimeters, 5 top/bottom layers; no supports intended
Carrier | Flat grid on bed, posts upward | 0.16 mm layers, 4 perimeters, 100% infill; no supports intended
Rear | Outside back face on bed, collars upward | 0.16–0.20 mm layers, 4 perimeters, 5 top/bottom layers; no supports intended
Stand | Plinth on bed | 0.16–0.20 mm layers, 4 perimeters, 100% infill; local PLA supports beneath the front detent leaves/tips
Coupons / key | As supplied | Same filament and fit-critical settings as the final parts

These settings have not been sliced for your printer. Inspect the layer preview, especially the stand's free-ended detent leaves, cable-channel bridges and latch tips. Use local support painting rather than filling every cavity with support. Clear all support from the cable passage before inserting a cable.

A 200 × 200 mm usable bed accommodates the largest 134 × 188 mm part, with a modest brim if the printer's actual usable area permits it. A 220 × 220 mm bed provides more margin. Do not scale parts to fit a smaller bed. Use filament-specific temperature settings and a clean bed; keep seams, first-layer bulges and support scars away from glass seats and mating faces.

Use ordinary unfilled PLA for the first article. Print coupons in the same spool and orientation. A decorative filament's snap behaviour can differ; no blend is certified here. Prusa notes PLA's relatively brittle behaviour and low temperature resistance. [S7]

### Calibration before the full build

The pin coupon has five nominal diameters, left to right along increasing X: 2.40, 2.50, 2.60, 2.70, 2.80 mm. Its companion has three Ø2.75 and two Ø3.00 holes. Printed holes only indicate your printing process; they do not replace checking a real PCB hole. Gently test a suitable individual peg with the actual PCB, supporting it at the hole. A board should lower onto its posts without being forced or flexed.

For the latch coupon, place the male part on the socket's open floor with the long leaf next to its rear wall and press down until the small head enters the window. The male underside ends 1 mm above the socket's print-bed plane. Release by pushing the head inward through the window. This tests a similar in-plane PLA leaf, not the entire case or stand interface. Reject cracked, whitened or permanently distorted samples.

Dry-fit the four full-size printed parts without electronics before assembling the glass. All clips should engage with modest, local finger pressure. Do not compensate for a tight print by pushing harder through the screen. Correct dimensions or printing settings and reprint.

## Assembly order

1. Bench-test the Pi and display. Install the microSD card and any required GPIO header before enclosure assembly. Check every dimension in the compatibility section, the FFC contact orientation, and the physical bendable regions of both flex cables.
2. Print and test the coupons, then the four structural parts. Remove stringing and support debris; smooth only the relevant printed mating surfaces. Confirm the empty front, carrier, lid and stand fit without force.
3. Lay the front bezel face-down on a clean, protective work surface. Lower the glass into its seat, image toward the aperture, bonded tail to the right as seen from the rear. Keep dust and printing burrs off the glass support border.
4. Position the carrier on its four bezel locating pins. Keep the bonded tail outside the carrier's relieved side pocket. Engage the four carrier tabs using pressure on the perimeter near each clip, not the crossbars over the glass. Verify the display is not bowed or squeezed.
5. Place the Pi, HAT and adapter on their respective four locating posts. Check every PCB sits on its standoff shoulders, not on a component or cable. The HAT's factory underside header is retained; no desoldering is assumed.
6. Connect the panel tail to the adapter with a gentle return. Connect the 50 mm FFC and arrange the broad arched route. Insert and lock connectors according to the kit instructions. The full seated contact ends must remain straight; do not pull the bonded tail to gain reach.
7. Connect the eight-wire HAT lead to the Pi, following the manufacturer pinout. Route it around the left side of the HAT, below its lower retention-post positions. Plug the slim micro-USB lead into PWR IN, not the data USB port, and place its jacket in the curved lower saddle.
8. With the unit still face-down, lower the rear cover squarely. Make sure each annular collar surrounds a peg rather than landing on a component. Check the entire cable route before engaging all four lid clips. The cover must not require force to flatten a ribbon or push down a connector.
9. Lay the external USB lead into the stand's open underside channel. Seat the case into the angled cradle and engage the two front detents. Confirm the cable is not trapped between the case and the stand and does not lift the stand off the worktop.
10. Power up. Check a full image, then check temperature, stability, cable slack and the absence of glass pressure during normal use. Stop using the enclosure if the display changes when the frame is gently handled, a plug is under load, a latch cracks or the plastic distorts.

For service: unplug power; support the frame; release the two stand detents and remove the case. Lay it face-down. Press the rear-cover tabs inward using the supplied PLA key and lift the cover evenly. Do not pry between glass and bezel. Release the carrier only when the screen itself needs removal. Removing the lid also removes axial retention from the PCBs.

## Kitchen placement

This is a vented indoor enclosure, not splash-proof, washable or IP-rated. There is no transparent protective sheet over the display. Keep it away from the hob, oven exhaust, toaster, kettle plume, sink splashes and direct hot sunshine. Do not wash or immerse it. Prusa states that ordinary PLA can soften and deform above approximately 60°C; that is not an acceptable target operating temperature. [S7]

The solid base improves the distribution of mass but cannot guarantee resistance to a cable snag or a forceful knock. Confirm stability on your actual worktop, first with the screen supported. All-PLA construction deliberately excludes elastomer anti-slip feet.

## Editing and regenerating

Open counterframe.scad, select part, and use F6 to render. For a printable export choose front, carrier, rear or stand, then export STL. assembly, exploded and section are inspection views. Toggle show_hardware and show_cables for clarity.

# Reproduce all manufacturing STLs (OpenSCAD must be installed).
bash export.sh

# A single part, or a tolerance variant.
openscad -o carrier.stl -D 'part="carrier"' counterframe.scad
openscad -o rear_no_grip.stl -D 'part="rear"' -D 'cable_grip=0' counterframe.scad

The short FFC arch uses ffc_arch_rise; it is not a route for an arbitrary cable length. The most useful fit adjustments are panel_t, panel_xy_clear, panel_z_clear, pi_peg_d, hat_peg_d, pcb_t, pcb_capture_clear, cable_d, cable_grip and fit. Changing a mating dimension means regenerating all affected parts, not just one. Never shrink the glass pocket to obtain an interference fit.

This is an editable design for a particular hardware arrangement, not a universally self-adapting enclosure generator. Board positions, plug keep-outs and the arched-cable route include fixed values. Substantial dimension changes require checking those features and rerunning clearance checks. The optional Python studio renderer's transforms are set for this delivered version; update them for altered dimensions. OpenSCAD's own assembly view uses the live parameters.

## Validation scope

validation.json records the checks actually completed on the exported meshes. A watertight, single-body STL is not proof that a snap fit will survive printing or use. Nominal CSG interference checks use simplified hardware keep-outs, omit small components and solder details, and intentionally allow the specified USB jacket compression. They do not measure real strength, thermal behaviour, grip, electrical safety, cable bend limits, manufacturing variation or impact resistance.

Before relying on the enclosure, the remaining first-article checks are actual hardware fit; printing/slicing; latch engagement and release; no preload on the glass; fully seated, unstrained flex connectors; non-damaging USB capture; normal-use temperatures; and stability/cable-pull behaviour on the intended counter.

## Manufacturer references

Dimensions were checked against these primary sources on 23 September 2026. Published component heights and a full exact mechanical model were not available in the reviewed material.

- S1 — Waveshare product identification: https://www.waveshare.com/7.3inch-e-paper-hat-e.htm
- S2 — Waveshare panel / active area / bonded tail drawing: https://www.waveshare.com/img/devkit/LCD/7.3inch-e-Paper-HAT-E/7.3inch-e-Paper-E-details-size.jpg
- S3 — Waveshare HAT and adapter mounting drawing: https://www.waveshare.com/img/devkit/LCD/7.3inch-e-Paper-HAT-E/7.3inch-e-Paper-HAT-E-details-size.jpg
- S4 — Waveshare assembly arrangement photograph: https://www.waveshare.com/img/devkit/LCD/7.3inch-e-Paper-HAT-E/7.3inch-e-Paper-HAT-E-details-5.jpg
- S5 — Raspberry Pi Zero mechanical drawing: https://datasheets.raspberrypi.com/rpizero/raspberry-pi-zero-mechanical-drawing.pdf
- S6 — Waveshare (E) manual, specifications and handling guidance: https://www.waveshare.com/wiki/7.3inch_e-Paper_HAT_(E)_Manual
- S7 — Prusa PLA material guidance: https://help.prusa3d.com/article/pla_2062

Required before the full print: confirm the exact (E) kit, obtain/check the matched 50 mm FFC, and measure the USB plug and jacket.

Generated enclosure code and meshes: CC0-1.0. Manufacturer documentation, brands and trademarks remain their respective owners' material. The screen artwork is illustrative content, not supplied display software.

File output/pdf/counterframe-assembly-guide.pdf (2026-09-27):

GARDEN INK / COUNTERFRAME

AN ILLUSTRATED BENCH GUIDE

# Build your Counterframe

Portrait e-ink enclosure for Garden Ink and Open Observatory


ASSEMBLY GUIDE / v1.0 CAD / 26 SEP 2026 | 01 / 09

4

structural
PLA prints
0

screws, inserts
or glue
1

external lead
into Pi PWR IN

Pi Zero + Waveshare
7.3-inch Spectra 6
HAT (E)

Project photograph: an assembled, working Garden Ink device.

Before you begin
This guide follows the v1.0 engineering-prototype CAD. The photograph does not establish its exact print revision. Physical fit, cable clearance, latch life, temperature and stability still need checking on your build.

Find your place Parts 2 · Printing 3 · Glass 4 · Boards & ribbons 5 Wiring 6 · Closing the case 7 · Power & service 8 · Build record 9

01 / PREPARE

# Gather and check the parts

Read this page before printing or ordering a replacement ribbon cable.

Item | What to have ready
Display kit | Waveshare 7.3-inch Spectra 6 HAT (E): glass panel, dedicated blue driver HAT and separate small FPC adapter. (F), (G) and other driver boards are not covered.
Pi + power | Pi Zero with required GPIO header and microSD installed; suitable Pi 5 V supply and slim, straight micro-USB lead. Check your actual Pi revision and component heights.
Interconnects | Eight-wire SPI/power harness; matched 50 mm overall, 50-way FFC with the kit’s correct pitch and contact-side arrangement. Measure the supplied cable; it may need replacing.
Printed parts | One front bezel, carrier, rear cover and stand. Four fit coupons; optional PLA release key. Use ordinary unfilled PLA for the first build.
Bench essentials | Clean protective work surface, calipers, small deburring tool or fine file, and a way to inspect small connectors. A reachable Open Observatory station is needed for live data.

## Measure against the CAD assumptions

Feature | Nominal model value
Glass / active area | 170.2 × 111.2 mm / 160 × 96 mm; model glass thickness 0.91 mm. Verify actual thickness and back features.
Board outlines | Pi: 65 × 30 mm; HAT: 65 × 30.5 mm; adapter: 45 × 21 mm. Check connectors and underside parts.
USB plug / jacket | Moulded plug body 9.6 × 14 × 5.6 mm; cable jacket diameter 3.4 mm. Bulky or right-angle plugs are not an assumed fit.

Check the flexible regions
Identify which parts of the panel tail and FFC may bend. Keep stiffeners, ICs, bonded transitions and seated contact ends straight. Never pull a tail to gain reach.

02 / PRINT AND DRY-FIT

# Prepare the four prints

All supplied manufacturing STLs are in millimetres and already oriented for printing.


CAD parts shown in print orientation. Print one of each from hardware/counterframe/stl/.

Part / file | Starting settings for a 0.4 mm nozzle
Front · front.stl | Visible face down; 0.16-0.20 mm layers, 4 perimeters, 5 top/bottom layers. No supports intended.
Carrier · carrier.stl | Grid down, posts up; 0.16 mm layers, 4 perimeters, 100% infill. No supports intended.
Rear · rear.stl | Outside face down, collars up; 0.16-0.20 mm layers, 4 perimeters, 5 top/bottom layers. No supports intended.
Stand · stand.stl | Plinth down; 0.16-0.20 mm layers, 4 perimeters, 100% infill. Local supports under front detent leaves/tips.

Test first. Print coupon_pins, coupon_holes, coupon_latch and coupon_socket in the same PLA and fit-critical settings. Check a suitable peg gently against a supported real PCB hole. Reject cracked, whitened or permanently bent latch samples.

Then dry-fit the empty case and stand. Remove stringing, burrs and cable-channel supports. Clips should engage with modest local pressure. Use a 200 × 200 mm usable bed or larger; inspect the slicer preview. Do not scale the parts or print reference electronics meshes.

03 / ASSEMBLY STEPS 1-3

# Seat the glass and carrier

Work face-down on a clean protective surface. Disconnect power before assembly.

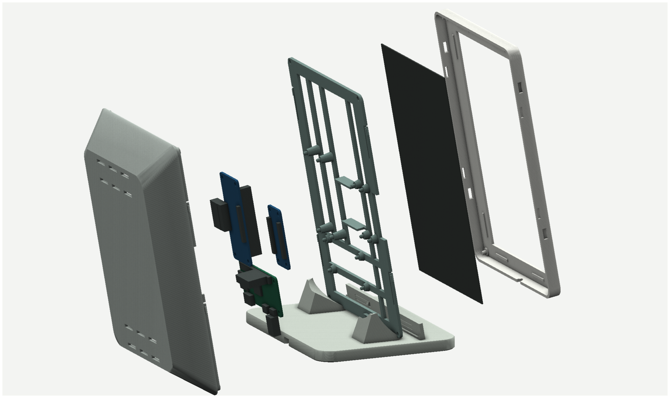
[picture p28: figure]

CAD exploded view: rear cover → boards → carrier → glass → front bezel. Cables omitted. The upright view is for orientation; assemble and service face-down.

### 1 Bench-test before enclosing

Check that the Pi and display operate together. Install the microSD and GPIO header first. Shut down and unplug power before changing connections or fitting the case.

### 2 Lower the panel into the bezel

Lay the bezel face-down. Place the glass with its image toward the aperture and bonded tail on the right as viewed from the open rear. Only the inactive border rests on the seat. Keep dust and burrs away from that border.

### 3 Engage the carrier’s four tabs

Align the carrier with the four bezel locating pins. Keep the tail clear in the relieved right-side pocket. Press the carrier perimeter near each clip, never its crossbars above the glass. Check the panel remains flat and is not squeezed.

The glass is captured, not clamped
Nominal clearance is 0.30 mm per side and 0.15 mm axially. The aperture centres the image; the unequal glass borders are intentional. If the carrier cannot latch without pressure on the glass, stop and correct the fit.

04 / ASSEMBLY STEPS 4-5

# Fit the boards and ribbons

All left/right directions below are viewed from the open rear.


### 4 Lower each board onto its four posts

Pi at the bottom; HAT above it on the left; small adapter on the right. Seat every PCB on its standoff shoulders, clear of components and cables. Keep the HAT’s factory underside header fitted.

### 5 Connect the two flexible cables

Return the panel’s bonded tail gently into the adapter’s outer socket. Connect the matched 50 mm FFC between adapter and HAT in one broad arch. Confirm contact orientation and operate each connector lock as specified for the kit. Keep seated ends straight; no edgewise folds, twists or creases.

Keep the assembly face-down
The boards can lift off their posts until the rear cover is fitted. Modelled bend radii (4.5 mm panel tail; about 6.7 mm FFC) are design assumptions, not approved minimums. Reject a route that bends an unsuitable part of the actual cable.

05 / ASSEMBLY STEP 6

# Wire the HAT and Pi

Power must be disconnected. Use the board’s physical pin numbering, not wire colours.

## 6 Connect the eight-wire harness

This table is the confirmed project arrangement for the dedicated HAT (E). Identify pin 1 and the header orientation on your actual Pi before connecting. Physical header pin numbers and BCM GPIO numbers are different.

HAT label | BCM / function | Physical Pi pin
BUSY | GPIO24 | 18
RST | GPIO17 | 11
DC | GPIO25 | 22
CS | GPIO8 / SPI0 CE0 | 24
SCLK | GPIO11 / SPI0 SCLK | 23
DIN | GPIO10 / SPI0 MOSI | 19
GND | Ground | 20
VCC | 3.3 V in this project setup | 17

HAT switch: 0 = 4-line SPI
GPIO8 chip select is controlled by hardware SPI. GPIO18 is not an extra display-power connection. Do not substitute a different Waveshare variant’s wiring.

## Route the harness clear of the retainers

Run wires left from the Pi, below the HAT’s lower mounting posts, then up the left side to its eight-pin connector. Keep wires away from all rear-cover collar positions. The coloured paths in the CAD images show routing only.

## Connect the one external power lead

Plug the slim micro-USB lead into the Pi’s PWR IN socket, not its USB data socket. Place the flexible jacket in the curved lower saddle. External 5 V enters the Pi through PWR IN; the table’s VCC connection is the project’s 3.3 V HAT connection.

06 / ASSEMBLY STEPS 7-8

# Close the case and fit the stand

Check cable clearance before engaging the rear-cover clips.


Left: rear-cover collars, viewed from inside. Right: closed case and underside cable exit. CAD views; board and cable clearances still need checking on your physical build.

### 7 Lower the rear cover squarely

Keep the frame face-down. The twelve annular collars must surround their pegs and capture the PCB mounting-hole lands, without landing on components, connector boots or wires. Inspect the entire ribbon and USB route, then engage all four cover clips. Do not use the lid to flatten a ribbon or push a connector down.

### 8 Seat the case in the stand

Place the external USB jacket in the stand’s open underside channel. Seat the closed case in the angled cradle and engage both front detents. Check the cable is not trapped and does not lift the base off the worktop. Leave slack behind the stand.

Check the USB saddle
Only the flexible jacket should be lightly captured; the plug and PCB connector must not take a pull. The default groove assumes 0.10 mm squeeze on a 3.4 mm jacket. If compressibility is unknown, start with cable_grip=0 and regenerate both carrier and rear cover. Never force a mismatched cable into the supplied print.

07 / FIRST USE AND SERVICING

# Power up, inspect and maintain

Garden Ink needs a reachable Open Observatory station for live observations.

### 9 Check the completed assembly

Apply power only after checking the wiring and closure. Confirm a full image, cable slack, firm clip engagement and stable placement. Monitor temperature and look for distortion during normal use. The enclosure must not put pressure on the glass.

Stop and inspect if something changes
Disconnect power if the image changes when the frame is gently handled, a connector is under load, a latch cracks or the plastic distorts. Do not push harder to make a tight part fit.

## Software setup

For a fresh Pi, follow docs/operations/DEPLOYMENT.md: install the display application, check station access, perform one panel refresh and then install the hourly service. The application uses the existing HAT (E) driver. No paid artwork generation is required.

A refresh may wait for the persisted hardware cooldown. Do not clear state or run competing panel demos to force it. When upgrading an existing device, preserve configuration, curated artwork, credentials and all state before replacing files.

## Open the enclosure for service

Shut down the Pi and unplug power. Support the frame; release both stand detents and lift the case out.

Lay the case face-down. Press the four rear-cover tabs inward with the PLA release key, and lift the cover evenly.

The PCBs are now free to lift off their posts. Keep the assembly flat and support boards when disconnecting cables.

Release the carrier only if the screen itself needs removal. Never pry between the bezel and glass.

## Choose a dry, cool location

Keep the vents clear and the frame away from cooking heat, kettle steam, splashes and hot sunlight. The PLA enclosure is not splash-proof or washable. Check stability on your own worktop; PLA can slide on polished or wet surfaces. Lift the finished device by its base.

08 / BUILD RECORD

# Check off your finished build

Keep these notes with the printed parts so future fit changes can be traced.

Exact HAT (E), Pi revision, board heights, USB plug and FFC contact arrangement checked.

Coupons passed; empty parts fitted; no damaged or whitened clips.

Glass lies flat with no preload; all four carrier clips are engaged.

All three boards sit on their shoulders; connectors are fully seated and locked.

Panel tail and FFC remain unstrained; wires clear the cover collars.

Four lid clips and both stand detents engaged; cable jacket held without damage.

Full image, normal-use temperature, cable slack and worktop stability checked.

Record | Your build
Date / CAD revision | ________________________________________________
Printer / PLA / layers | ________________________________________________
Fit changes / cable details | ________________________________________________
Temperature / fit notes | ________________________________________________

## Sources and further detail

Construction guide · hardware/counterframe/README.md (https://github.com/simonjgreen/OpenObservatory-GardenInk/blob/main/hardware/counterframe/README.md)

Master CAD · hardware/counterframe/counterframe.scad (https://github.com/simonjgreen/OpenObservatory-GardenInk/blob/main/hardware/counterframe/counterframe.scad)

Project wiring · docs/design/MECHANICAL.md (https://github.com/simonjgreen/OpenObservatory-GardenInk/blob/main/docs/design/MECHANICAL.md)

Pi installation and upgrades · docs/operations/DEPLOYMENT.md (https://github.com/simonjgreen/OpenObservatory-GardenInk/blob/main/docs/operations/DEPLOYMENT.md)

Manufacturer handling and connections · Waveshare HAT (E) manual (https://www.waveshare.com/wiki/7.3inch_e-Paper_HAT_(E)_Manual)

Prepared from the repository’s v1.0 CAD and current project notes on 26 September 2026. CAD renders are illustrations of the supplied geometry, not proof of physical fit. This guide adds no hardware qualification. Enclosure CAD/meshes: CC0; photographs, artwork and manufacturer material retain their separate terms.

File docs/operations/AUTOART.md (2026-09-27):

# Automatic missing artwork

Optional paid generation runs separately from the display and is disabled by default. Use the current application in `display/`; see [deployment](DEPLOYMENT.md) for installation.

## Opt into automatic missing artwork

Unattended paid requests are **disabled by default**. The Pi requires internet access for a *new* illustration; ordinary observation fetching still uses your local station, and cached/curated art works offline from OpenAI.

From your configured Pi installation:

```bash
cd ~/garden_ink
./autoart.sh enable
./autoart-service.sh install
./autoart.sh scan
```

`enable` shows the model, limits, data being sent and automatic-publication choice. It requires typing `ENABLE`, then prompts for the key without echo. The key is saved on the Pi as `~/garden_ink/.secrets/openai-api-key`, inside a mode-700 directory; the file has mode 600. Do not send it in chat. A dedicated API project/key is preferable to reusing a widely shared credential.

If a valid saved key exists, it is reused. Use `./autoart.sh enable --replace-key` to replace it. This is a separate credential from OpenObservatory's optional token. Do not put either into the other's configuration.

`autoart-service.sh install` enables the separate `garden-ink-art.service` worker at boot. `autoart.sh scan` fetches the station once and queues eligible missing species without refreshing the physical screen. It is optional: the display will also queue eligible gaps after each successful real hourly update. Check/preview/demo commands do not queue paid work.

### How it works

1. Use your already-filtered real-microphone bird identifications, respecting the display's score and human-review handling.
2. Queue missing artwork on the **first qualifying detection record** seen in a successful display report. This retains source, score, review and withdrawal filtering; it does not prove an identification correct. `min_detections` defaults to 1. An explicitly configured higher threshold is still respected, with a reviewed latest identification able to bypass it. Existing installations must set `min_detections` to 1 in `autoart.json` to adopt the new default. The worker retains its durable request limits, global spacing and no-automatic-retry policy.
3. Resolve scientific-name aliases and look for an existing custom, automatically cached or bundled image. Existing artwork is **not regenerated**. This is gap filling, not a replacement for installing the consistent collection you already generated.
4. Prioritise the main illustration and four daily cards, then other qualifying species encountered in the two windows.
5. Queue once per canonical species in SQLite. Fresh observations refresh eligibility but never reset a completed, failed, rejected or uncertain job. Jobs not observed in the preceding 24 hours, or belonging to an old station/filter configuration, do not start automatically.
6. A separate process performs the image edit using the **same original robin PNG** and the same original style brief. Every request also asks for one bird with exactly two legs and at most two visible feet. Completed images never become the next style reference.
7. Keep the raw response and preparation metadata, prepare a white-background PNG, and publish it atomically to the local generated-art cache. A suspect clipped/full-background image is held for inspection instead of being auto-published.
8. The running display checks every 30 seconds for newly available illustrations in the page it is showing: the main bird and four daily cards in the journal, or the six gallery cards. Relevant artwork triggers a redraw of that same historical report and layout, retaining the saved **180-second minimum between panel attempts**. Arrivals during that guard are combined, identical frames are skipped, and the next scheduled report takes priority. Artwork for other species waits until a report includes it. Review candidates do not trigger redraws. Generation never blocks the display, and the worker itself never drives the panel.

### What leaves the Pi

The fixed request goes to `https://api.openai.com/v1/images/edits`. It includes the scientific bird name, standard artistic instructions (and an optional operator correction note), and the reference robin PNG. Known catalogue species may use the catalogue's standard common name and pose instructions.

It does **not** send the audio, your station's URL, coordinates, detection times, counts, screenshots or credentials to the prompt. The API key is sent only as authentication to OpenAI over verified HTTPS; redirects are refused. No other model, image search, or fallback provider is called. Standard system HTTPS proxy configuration may apply if you configured one yourself.

The model stays pinned to `gpt-image-2-2026-04-21`, high quality, 1536 × 1024, one image per call. Input fidelity is not set for this model. We deliberately do not switch an existing consistent collection to a newer model alias.

## Cost and concurrency controls

Default settings in `autoart.json`:

```json
{
  "enabled": false,
  "model": "gpt-image-2-2026-04-21",
  "max_requests_per_24h": 2,
  "max_requests_total": 20,
  "workers": 2,
  "min_detections": 1,
  "timeout_seconds": 1200,
  "auto_publish": true
}
```

Once enabled, two independent requests may be in flight; starts are spaced at least 15 seconds apart. Local PNG preparation is serialised to limit memory use on a Pi Zero. This is not the old serial 53-image production loop.

Limits count **reserved attempt slots**, including failed and uncertain calls, and persist in SQLite across service restarts. A slot is recorded before submitting a paid request. A crash before submission can therefore conservatively consume a slot even though no call was sent. The rolling-24-hour cap avoids doubling at midnight. The total cap prevents an unattended appliance spending forever. These are **request-count caps, not exact currency caps**; billing depends on the model's actual input/output usage.

When a cap is reached, the display continues normally. Pending jobs wait; they are not discarded. Increase a limit deliberately, for example:

```bash
./autoart.sh enable --daily-limit 4 --total-limit 40
```

Previously used attempts remain counted; raising the total to 40 does not reset the counter. Do not delete the database to clear an error or “fix” a cooldown: that would erase both recovery and spending history.

## Anatomy and visual review

Automatic generation is not automatic anatomical or taxonomic validation. The software can verify file type, dimensions, blank output and crude edge clipping, **not whether a drawing has an extra leg or the correct plumage**. A diagram-perfect PNG can still be biologically wrong.

After opting in normally, useful-looking new PNGs are published automatically. They remain AI-generated decorative illustrations, not captured evidence or human-approved field-guide plates. A visible name on the display remains the acoustic classifier/reviewer's claim, not validation supplied by the illustration.

For generation without automatic publication:

```bash
./autoart.sh enable --review-required
```

This still generates and caches the missing image automatically, but you must approve it before it appears on the display. It does not retrospectively remove already published images.

To inspect:

```bash
./autoart.sh status
./autoart.sh review
```

`status` shows settings, counters, per-species state and provider pause state; it never prints the key. `review` writes `state/autoart/review.html` with local candidate images and no remote scripts/resources. Copy that directory to your workstation to browse it (no API key lives in that directory):

```bash
scp -r USER@DISPLAY-PI:~/garden_ink/state/autoart ./garden-ink-art-review
```

For operator edits, stop the artwork worker first; the display service can remain running. Commands deliberately refuse to race an in-flight generation:

```bash
./autoart-service.sh stop
./autoart.sh approve "Certhia familiaris"
./autoart-service.sh start
```

To reject a poor **auto-generated** image and explicitly queue a new paid attempt:

```bash
./autoart-service.sh stop
./autoart.sh reject "Certhia familiaris"
./autoart.sh retry "Certhia familiaris" --note "Exactly two legs; avoid duplicate feet. Preserve the reference drawing style."
./autoart-service.sh start
```

The retry asks for confirmation, preserves old raw/candidate files, and still obeys the request caps. It does not overwrite a separately installed custom or bundled image. For replacing an existing curated/bundled illustration, use the workstation art-studio regeneration workflow and install its approved result as before.

## Failure behaviour

- **Timeout, connection loss, invalid response or interrupted worker:** mark the attempt uncertain; no automatic POST retry. A request may already have been processed/charged.
- **Raw response saved, local preparation interrupted:** keep it. Worker restart can attempt local preparation without another API call. Manual recovery: stop the art worker and run `./autoart.sh recover "Scientific name"`.
- **Authentication, access/model errors, quota/rate response:** pause new requests across the queue. Already in-flight requests may finish. The display still works. Resolve the problem, then run `./autoart.sh resume`. Failed/uncertain species need a separate explicit `retry`; resuming does not resend them.
- **Unexpected drawing:** reject locally. There is no silent paid “try until good” loop.
- **No network/OpenAI issue:** observation display is unaffected. Missing imagery remains a labelled botanical fallback until a usable image is available.
- **Service restart:** previously requesting jobs become uncertain, not queued. Raw files from a completed response can be recovered locally.

To turn off paid requests:

```bash
./autoart.sh disable
```

This prevents new requests; one already in flight may still finish and save its image. Cached/curated images remain available. To stop the worker process as well: `./autoart-service.sh stop` (allows in-flight work to finish).

## File locations and service isolation

- `autoart.json`: opt-in policy, not a secret.
- `.secrets/openai-api-key`: owner-only credential; do not include it in publicly shared backups.
- `state/autoart/jobs.sqlite3`: durable job and attempt ledger, including spending limits' history.
- `state/autoart/raw/`: raw PNG responses and metadata, named by species and attempt ID.
- `state/autoart/candidates/`: prepared images awaiting/recovering from review.
- `state/autoart/images/`: published generated-art cache.
- `assets/custom/`: existing curated artwork. This always takes precedence, including mapped scientific aliases.
- `autoart_reference/`: fixed original robin, common style brief and species guidance.

Both services run under the normal Pi user. The art worker can write only under the application's `state/` directory in its systemd filesystem sandbox, has private devices, and has no panel/GPIO dependency. The application/reference/key directories are read-only to it. These are defence-in-depth settings, not a promise to withstand a compromise of the same Pi user. The worker does not control the physical display.

Services:

```bash
./service.sh status
./service.sh logs
./autoart-service.sh status
./autoart-service.sh logs
./autoart-service.sh diagnose
```

Reinstalling/removing the art service does not erase images, the key or counters. Keep your installation path stable.

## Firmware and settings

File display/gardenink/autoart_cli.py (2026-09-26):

"""Operator controls. Paid work is performed only by the explicitly enabled worker."""
from __future__ import annotations
import argparse
import getpass
import html
import json
import logging
import os
from pathlib import Path
import sys
import time
from .config import ROOT,load
from . import autoart as a
from .artfiles import identity


def confirm(word,message):
    if input(message+' Type '+word+': ').strip()!=word:
        raise ValueError('Cancelled; no changes made')


def review(store):
    cards=[]
    for job in store.rows():
        path=store.prepared(job)
        image=('<img src="%s" alt="%s">'%(html.escape(path.relative_to(store.root).as_posix(),quote=True),html.escape(job['scientific'],quote=True))) if path.is_file() else '<p>No prepared image.</p>'
        cards.append('<article><h2>%s</h2><p><i>%s</i> · %s</p>%s<p>%s</p></article>'%(
            html.escape(job['label']),html.escape(job['scientific']),html.escape(job['status']),image,html.escape(job['message'])))
    text='''<!doctype html><html><meta charset="utf-8"><title>Garden Ink — automatic artwork review</title>
<style>body{font-family:system-ui;max-width:1200px;margin:2em auto;padding:1em}section{display:grid;grid-template-columns:repeat(auto-fit,minmax(250px,1fr));gap:1em}article{border:1px solid #aaa;padding:1em}img{width:100%;height:230px;object-fit:contain}h2{font-size:1.1em}</style>
<h1>Generated illustrations</h1><p>AI-generated decoration, not camera evidence. Inspect anatomy and species identity. Automatic publication is not human approval.</p><section>'''+''.join(cards)+'</section></html>'
    a.atomic(store.root/'review.html',text.encode())
    print('Local review:',store.root/'review.html')


def main(argv=None):
    p=argparse.ArgumentParser(description='Garden Ink optional on-device missing-art generation')
    sub=p.add_subparsers(dest='cmd',required=True)
    en=sub.add_parser('enable',help='Opt into paid generation and save a key with hidden input')
    en.add_argument('--daily-limit',type=int,default=None)
    en.add_argument('--total-limit',type=int,default=None)
    en.add_argument('--review-required',action='store_true')
    en.add_argument('--replace-key',action='store_true')
    for name in ('disable','status','review','scan','resume'):sub.add_parser(name)
    worker=sub.add_parser('worker');worker.add_argument('--once',action='store_true')
    for name in ('approve','reject','recover','retry'):
        q=sub.add_parser(name);q.add_argument('species')
        if name=='retry':q.add_argument('--note',default='')
    args=p.parse_args(argv)
    logging.basicConfig(level=logging.INFO,format='%(asctime)s %(levelname)s %(message)s')
    if args.cmd=='worker':a.run_worker(args.once);return 0
    cfg=a.settings()
    if args.cmd=='enable':
        if args.daily_limit is not None:cfg['max_requests_per_24h']=args.daily_limit
        if args.total_limit is not None:cfg['max_requests_total']=args.total_limit
        cfg['auto_publish']=not args.review_required
        # Validate proposed values without overwriting a valid configuration first.
        if type(cfg['max_requests_per_24h']) is not int or not 1<=cfg['max_requests_per_24h']<=20:
            raise ValueError('daily-limit must be 1..20')
        if type(cfg['max_requests_total']) is not int or not 1<=cfg['max_requests_total']<=1000:
            raise ValueError('total-limit must be 1..1000')
        print('Enable PAID OpenAI image edits for missing, qualifying species only.')
        print('Sends scientific species identity, fixed style brief and original robin PNG.')
        print('Does NOT send recordings, coordinates, station URL, counts or detection times.')
        print('Model:',cfg['model'],'| high quality | 1536x1024 | timeout:',cfg['timeout_seconds'])
        print('Request caps:',cfg['max_requests_per_24h'],'per rolling 24h;',cfg['max_requests_total'],'total, including previous attempts.')
        print('These are request caps, NOT hard currency caps. API billing is separate.')
        print('Automatic publication:',cfg['auto_publish'],'(image anatomy is NOT automatically verified).')
        confirm('ENABLE','Accept these settings and paid requests?')
        if not a.secret_path().exists() or args.replace_key:
            key=getpass.getpass('OpenAI API key (hidden; saved only on this Pi): ').strip()
            if not key or len(key)>8192 or not key.isascii() or any(c.isspace() for c in key):
                raise ValueError('Invalid key format; no key saved')
            parent=a.secret_path().parent
            parent.mkdir(mode=0o700,parents=True,exist_ok=True);parent.chmod(0o700)
            a.atomic(a.secret_path(),key.encode())
        a.read_key()
        cfg['enabled']=True;a.save_settings(cfg)
        a.Store().pause('')
        print('Enabled. Install worker: ./autoart-service.sh install')
        print('Queue current missing birds without a screen refresh: ./autoart.sh scan')
        return 0
    if args.cmd=='disable':
        cfg['enabled']=False;a.save_settings(cfg)
        print('Disabled. No new jobs will be submitted. Already in-flight requests may finish.')
        return 0
    store=a.Store()
    if args.cmd=='status':
        print(json.dumps({'settings':cfg,'budget':store.budget(),'jobs':store.rows()},indent=2));return 0
    if args.cmd=='review':review(store);return 0
    if args.cmd=='scan':
        if not cfg['enabled']:raise ValueError('Automatic artwork is disabled; use enable first')
        from .client import Client
        display=load(ROOT/'config.json').validate()
        snapshot=Client(display,display.token(ROOT/'config.json')).fetch()
        print('New jobs queued:',a.enqueue_snapshot(snapshot,display),'; no physical refresh performed.')
        return 0
    if args.cmd=='resume':
        confirm('RESUME','Resume the queue after resolving provider access/quota/rate issues?')
        store.pause('')
        print('Queue resumed. Failed/uncertain species still require an explicit retry.')
        return 0
    # Local operator edits require the worker stopped; never race publication/retry.
    try:
        with a.worker_lock(store):
            slug,_=identity(args.species)
            job=store.job(slug)
            if job['status']=='requesting':
                # A stopped worker may have been killed during an HTTP request.
                store.finish(job,'uncertain','Interrupted request; retry may charge again')
                job=store.job(slug)
            if args.cmd=='approve':
                data=store.prepared(job).read_bytes()
                a.normalise(data)  # validation only, preserve original candidate bytes
                confirm('APPROVE','Visually checked this species and its anatomy?')
                a.atomic(store.root/'images'/(slug+'.png'),data)
                store.finish(job,'ready','Human approved locally')
                print('Approved; available to next scheduled display edition.')
            elif args.cmd=='reject':
                confirm('REJECT','Remove this auto-generated illustration from future editions?')
                store.finish(job,'rejected','Rejected by operator; no automatic regeneration')
                (store.root/'images'/(slug+'.png')).unlink(missing_ok=True)
                print('Rejected. Custom/bundled art is untouched. Existing panel image waits for next hourly update.')
            elif args.cmd=='recover':
                if not store.raw(job).is_file():raise ValueError('No local raw response to recover; cannot retrieve a lost server result')
                print('Recovered:',a.publish(store,job,cfg),'; no API request made.')
            elif args.cmd=='retry':
                if not cfg['enabled']:raise ValueError('Automatic artwork is disabled')
                if len(args.note)>1500:raise ValueError('Keep correction note below 1500 characters')
                confirm('RETRY','One NEW paid request when budget permits; an uncertain previous request may already have been charged. Proceed?')
                source=load(ROOT/'config.json').validate().identity()
                with store.db() as db:
                    db.execute("UPDATE jobs SET status='queued',note=?,message='',last_seen=?,source_identity=? WHERE slug=?",
                               (args.note or job['note'],time.time(),source,slug))
                (store.root/'images'/(slug+'.png')).unlink(missing_ok=True)
                print('Queued for a new attempt; raw history and request counters retained. Start the worker again.')
        return 0
    except RuntimeError as exc:
        if 'worker' in str(exc):raise RuntimeError('Stop ./autoart-service.sh before approval/rejection/recovery/retry') from None
        raise


def entry():
    try:return main()
    except (OSError,ValueError,RuntimeError) as exc:
        print('ERROR:',exc,file=sys.stderr);return 1

if __name__=='__main__':raise SystemExit(entry())

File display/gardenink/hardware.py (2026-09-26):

"""7.3-inch six-colour (E) ONLY. Adapted from Waveshare epd7in3e, MIT.
See NOTICE.txt for the complete upstream licence and reviewed source SHA.
No GPIO libraries are imported until a real hardware update is requested.
"""
from __future__ import annotations
import logging
import time
from pathlib import Path
from .palette import pack

LOG=logging.getLogger(__name__)
INIT_SEQUENCE=(
    (0xAA,(0x49,0x55,0x20,0x08,0x09,0x18)),
    (0x01,(0x3F,)),(0x00,(0x5F,0x69)),
    (0x03,(0x00,0x54,0x00,0x44)),(0x05,(0x40,0x1F,0x1F,0x2C)),
    (0x06,(0x6F,0x1F,0x17,0x49)),(0x08,(0x6F,0x1F,0x1F,0x22)),
    (0x30,(0x03,)),(0x50,(0x3F,)),(0x60,(0x02,0x00)),
    (0x61,(0x03,0x20,0x01,0xE0)),(0x84,(0x01,)),(0xE3,(0x2F,)),
)

class DisplayError(RuntimeError): pass

class PiIO:
    def __init__(self, settings):
        self.spi=None; self.pins=[]; self.rst=self.dc=self.busy=None
        if not Path('/dev/spidev0.0').exists():
            raise DisplayError('SPI0 missing: enable SPI in sudo raspi-config, then reboot')
        try:
            import spidev
            from gpiozero import DigitalOutputDevice, DigitalInputDevice
            self.spi=spidev.SpiDev()
            self.spi.open(0,0)
            self.spi.max_speed_hz=settings.spi_speed_hz
            self.spi.mode=0
            # CE0 is driven by the SPI kernel driver. Do NOT claim GPIO8 separately.
            self.rst=DigitalOutputDevice(17,initial_value=True);self.pins.append(self.rst)
            self.dc=DigitalOutputDevice(25,initial_value=False);self.pins.append(self.dc)
            # A disconnected BUSY should read low and time out, not look instantly complete.
            self.busy=DigitalInputDevice(24,pull_up=False);self.pins.append(self.busy)
        except Exception as exc:
            self.close()
            raise DisplayError('SPI/GPIO setup failed: %s. Check packages and gpio/spi groups.' % exc) from exc

    def reset(self,value): self.rst.value=value
    def command(self,value):
        self.dc.off(); self.spi.writebytes([value])
    def data(self,values):
        self.dc.on()
        self.spi.writebytes2(bytes(values))
    def ready(self): return bool(self.busy.value)
    def close(self):
        if self.spi is not None:
            try:self.spi.close()
            except Exception:pass
        for pin in reversed(self.pins):
            try:pin.close()
            except Exception:pass
        self.pins=[]

class EPD:
    def __init__(self,settings,io=None):
        self.settings=settings;self.io=io;self.initialised=False

    def wait_idle(self):
        time.sleep(0.02)
        deadline=time.monotonic()+self.settings.busy_timeout_seconds
        while not self.io.ready():
            if time.monotonic()>=deadline:
                raise DisplayError('BUSY timed out. Check GPIO24 (physical 18), VCC/GND, '
                                   'ribbon seating and switch 0 / 4-line SPI. No rapid retry.')
            time.sleep(0.01)

    def initialise(self):
        if self.io is None:self.io=PiIO(self.settings)
        self.io.reset(1);time.sleep(.02)
        self.io.reset(0);time.sleep(.002)
        self.io.reset(1);time.sleep(.02)
        self.wait_idle();time.sleep(.03)
        for cmd,data in INIT_SEQUENCE:
            self.io.command(cmd);self.io.data(data)
        self.io.command(0x04);self.wait_idle()
        self.initialised=True

    def show(self,frame):
        buf=pack(frame,self.settings.rotation)
        if len(buf)!=192000:raise DisplayError('Wrong frame length')
        self.initialise()
        self.io.command(0x10);self.io.data(buf)
        self.io.command(0x04);self.wait_idle()
        started=time.monotonic()
        self.io.command(0x12);self.io.data([0x00]);self.wait_idle()
        elapsed=time.monotonic()-started
        self.io.command(0x02);self.io.data([0x00]);self.wait_idle()
        if elapsed<1.0:
            raise DisplayError('BUSY returned in under one second: this is not a normal full '
                               'colour refresh. Check BUSY wiring before treating it as success.')
        LOG.info('Panel full refresh completed in %.1fs',elapsed)

    def close(self):
        if self.io is None:return
        try:
            # Use the normal deep-sleep command even after an interrupted update.
            self.io.command(0x07);self.io.data([0xA5]);time.sleep(2)
        except Exception:pass
        finally:self.io.close();self.io=None


def display(frame,settings):
    epd=EPD(settings)
    try:epd.show(frame)
    finally:epd.close()

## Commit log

2026-09-26 Publish Garden Ink as an Open Observatory companion
    [adapter_pcb.stl, carrier.stl, carrier_rear.scad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]
2026-09-26 Pin current CI actions and Ubuntu runner
2026-09-26 Credit Fugleramme inspiration and illustrate the frame build
2026-09-27 Strengthen artwork colour and add guarded push refresh
    Preserve feather detail while increasing colour wash coverage. Refresh on
    startup and provide service.sh refresh and --refresh-now, retaining the
    persisted 180-second minimum and normal hourly report scheduling.
    Verified the isolated commit snapshot with 231 offline tests and a native
    480x800 preview. The test Pi completed a strong-wash pushed refresh.
    [app.py, render.py]
2026-09-27 Generate missing art on first detection and redraw relevant pages
    [app.py, autoart.py, render.py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]
2026-09-27 Add illustrated Counterframe assembly guide PDF
